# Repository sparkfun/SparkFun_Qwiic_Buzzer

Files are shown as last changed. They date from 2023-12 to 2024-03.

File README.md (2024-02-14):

SparkFun Qwiic Buzzer
========================================

SparkFun Qwiic Buzzer (https://www.sparkfun.com/products/24474)

[*SparkFun Qwiic Buzzer (BOB-24474)*](https://www.sparkfun.com/products/24474)

The SparkFun Qwiic Buzzer adds simple beeps and buzzes to your projects via I<sup>2</sup>C Make some noises to alert you when something interesting (or urgent) happens. Simply connect a Qwiic cable and load up some pre-written code to an Arduino to start making noises!

The board includes an ATtiny84 with custom firmware to control the piezoelectric buzzer over I<sup>2</sup>C. Utilizing our handy Qwiic system, no soldering is required to connect it to the rest of your system. However, we still broke out 0.1"-spaced PTH pads if you prefer to use a breadboard to access the board's I2C, power, trigger, and reset pins on the board's edge. A 2.2k&ohm; pull-up resistor is included on the data and clock lines. 

A set of transistors control the buzzer's volume. At full volume, it allows the full current of about ~95mA, which makes it _really_ loud. A flyback diode is included to discharge any energy remaining when the buzzer is turned off. For those who want to control the loudness of the buzzer, a footprint is available to solder a custom PTH resistor to one of the transistors. Just make sure to cut the jumper labeled "JP1." Two LEDs are also included on the board for power and status. 

We've written an Arduino Library to control the volume, frequency, duration, and I<sup>2</sup>C address. There are even examples of how to play a quick melody and sweet sound effects! You can download the library through the Arduino library manager by searching 'SparkFun Qwiic Buzzer,' or you can get the GitHub repo as a .zip to install the library from there manually. For those who want a simple buzz without an Arduino, you can also make noise by simply grounding the trigger pin! We've even ported the library as a Python package! 

This board is great for adding a simple audible sound to your projects. Pair the board with the Qwiic RTC to make an alarm clock, play a tune with the Qwiic RFID, or add a sound effect to your robot. So what are you waiting for?!? Start making some noise in your projects with the SparkFun Qwiic Buzzer!

Repository Contents
-------------------

* **.github/workflows** - YAML files used for GitHub Actions and GitHub Pages/mkdocs
* **/Firmware** - ATtiny84 Firmware
* **/Hardware** - Eagle design files (.brd, .sch)
  * **/Production** - Production panel files (.brd)
* **/docs** - Online documentation files
  * **/assets** - Folder containing all the file assets used for product documentation
    * **/board_files** - Copy of design files used for product documentation
    * **/component_documentation** - Datasheets and manuals for hardware components
    * **/img** - Images for product documentation
  * **/github** - Files stating how to contribute and filing issues used for product documentation
  * **/javascript** - Folder containing custom javascript used for product documentation
  * **/stylesheet** - Folder containing CSS files used for product documentation
* **/overrides** - Customization files used for product documentation
  * **/.icons** - Icons used for GitHub used for product documentation
  * **./partials** - Used for product documentation

Documentation
--------------

* **[Installing an Arduino Library Guide](https://learn.sparkfun.com/tutorials/installing-an-arduino-library)** - Basic information on how to install an Arduino library.
* **[Library](https://github.com/sparkfun/SparkFun_Qwiic_Buzzer_Arduino_Library)** - Arduino library for the Qwiic Buzzer.
* **[Hookup Guide](https://docs.sparkfun.com/SparkFun_Qwiic_Buzzer)** - Basic hookup guide for the  Qwiic Buzzer.

Product Versions
----------------
* [BOB-24474](https://www.sparkfun.com/products/24474) - v1.0

Version History
---------------
* v1.0 - Initial release

License Information
-------------------

This product is _**open source**_! 

Please review the LICENSE.md file for license information. 

If you have any questions or concerns on licensing, please contact technical support on our [SparkFun forums](https://forum.sparkfun.com/viewforum.php?f=152).

Distributed as-is; no warranty is given.

- Your friends at SparkFun.

_<COLLABORATION CREDIT>_

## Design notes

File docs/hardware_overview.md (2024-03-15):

In this section, we will highlight the hardware and pins that are broken out on the SparkFun Qwiic Buzzer.

<div style="text-align: center;">
  <table>
    <tr style="vertical-align:middle;">
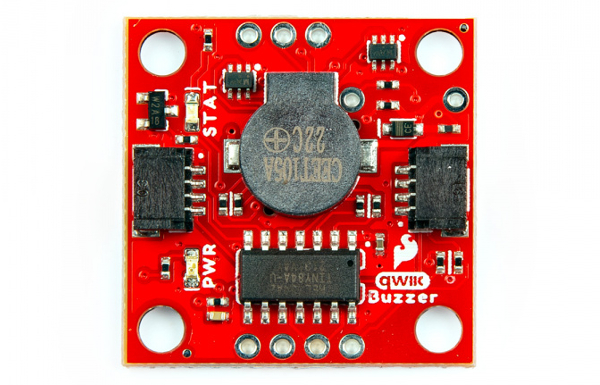
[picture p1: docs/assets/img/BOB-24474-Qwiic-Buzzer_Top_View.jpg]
Top View
     <td style="text-align: center; border: solid 1px #cccccc; vertical-align: middle;"></td>
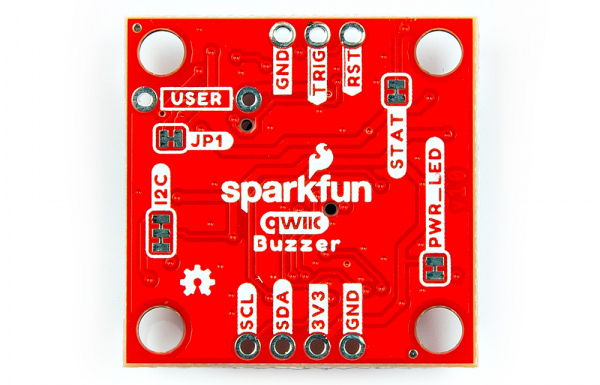
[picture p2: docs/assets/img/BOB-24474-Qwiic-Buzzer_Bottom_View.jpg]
Bottom View
     <td style="text-align: center; border: solid 1px #cccccc; vertical-align: middle;"></td>
    </tr>
    <tr style="vertical-align:middle;">
     <td style="text-align: center; border: solid 1px #cccccc; vertical-align: middle;"><i>Top View</i></td>
     <td style="text-align: center; border: solid 1px #cccccc; vertical-align: middle;"><i>Bottom View</i></td>
    </tr>
  </table>
</div>

### Power

There are a few power-related nets broken out to Qwiic connectors and through hole pads. The recommended input voltage is **3.3V**. The logic levels for the Qwiic Buzzer is **3.3V**.

* **3V3** &mdash; This connects to the 3.3V net. This net should only be provided with a clean 3.3V power signal. This is also connected to the Qwiic connectors.
* **GND** &mdash; Of course, is the common, ground voltage (0V reference) for the system.

<div style="text-align: center;">
  <table>
    <tr style="vertical-align:middle;">
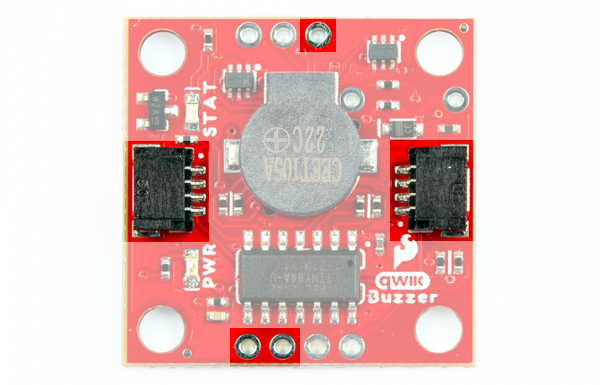
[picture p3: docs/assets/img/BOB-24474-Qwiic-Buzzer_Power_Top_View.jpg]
Power Nets Highlighted, Top View
     <td style="text-align: center; border: solid 1px #cccccc; vertical-align: middle;"></td>
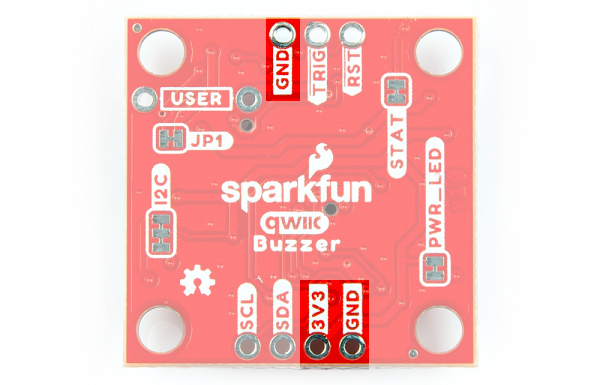
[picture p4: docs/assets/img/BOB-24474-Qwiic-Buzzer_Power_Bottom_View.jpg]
Power Nets Highlighted, Bottom View
     <td style="text-align: center; border: solid 1px #cccccc; vertical-align: middle;"></td>
    </tr>
    <tr style="vertical-align:middle;">
     <td style="text-align: center; border: solid 1px #cccccc; vertical-align: middle;"><i>Power Nets Highlighted<br />(Top View)</i></td>
     <td style="text-align: center; border: solid 1px #cccccc; vertical-align: middle;"><i>Power Nets Highlighted<br />(Bottom View)</i></td>
    </tr>
  </table>
</div>

!!! note
    While the ATtiny84 microcontroller can handle a voltage between 1.1V to 5.5V, we recommend only using 3.3V due to the fact that the Qwiic port's I<sup>2</sup>C data lines use are typically interfacing with a 3.3V system.

### Buzzer

!!! note
    Interested in the difference between a magnetic and piezo buzzer? Check out the article from CUI Devices: "[Buzzer Basics - Technologies, Tones, and Drive Circuits](https://www.cuidevices.com/blog/buzzer-basics-technologies-tones-and-driving-circuits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)".

The board would not be the Qwiic Buzzer without... a buzzer! The buzzer uses a small magnetic coil to vibrate a metal disc inside the plastic housing. By pulsating current through the coil at different rates, we can produce different frequencies (pitches) of sound.

<div style="text-align: center;">
  <table>
    <tr style="vertical-align:middle;">
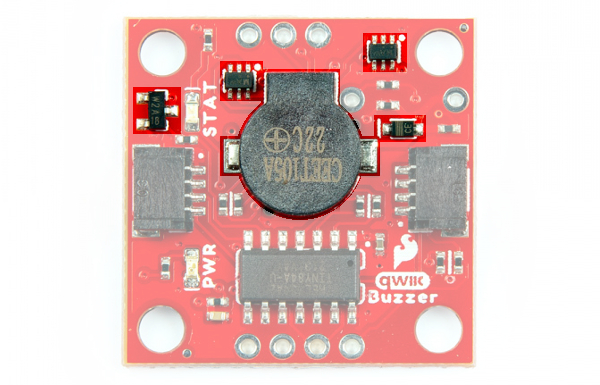
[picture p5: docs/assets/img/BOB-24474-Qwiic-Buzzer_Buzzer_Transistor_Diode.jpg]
Buzzer Highlighted
      <td style="text-align: center; border: solid 1px #cccccc; vertical-align: middle;"></td>
    </tr>
    <tr style="vertical-align:middle;">
      <td style="text-align: center; border: solid 1px #cccccc; vertical-align: middle;"><i>Buzzer Highlighted<br />(Top View)</i></td>
    </tr>
  </table>
</div>

Power and control is applied to the buzzer with a set of BJTs. At full volume, it allows the full current of about ~95mA, which makes it _really_ loud. Typically, power and control is directly connected to microcontrollers GPIO, which limits the current to ~40mA. A [flyback diode](https://learn.sparkfun.com/tutorials/diodes/all#diode-applications) is included to discharge any energy remaining when the buzzer is shut off.

### ATtiny84

The brains of the Qwiic Buzzer users an ATtiny84. This IC comes pre-programmed with custom firmware designed to interact with the Arduino Library. The ATtiny84 accepts I<sup>2</sup>C reads and writes, interprets them, and creates sound by sending a PWM signal to the buzzer. The volume of the buzzer is typically controlled using a variable resistor like a potentiometer. However, four GPIOs, NPN transistors, and resistors are used to provide 7 levels of loudness.

<div style="text-align: center;">
  <table>
    <tr style="vertical-align:middle;">
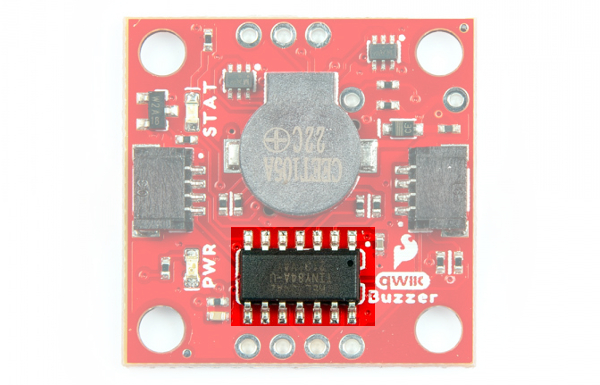
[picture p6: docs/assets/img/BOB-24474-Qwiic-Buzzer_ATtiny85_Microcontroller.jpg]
ATtiny84 microcontroller Highlighted
     <td style="text-align: center; border: solid 1px #cccccc; vertical-align: middle;"></td>
    </tr>
    <tr style="vertical-align:middle;">
      <td style="text-align: center; border: solid 1px #cccccc; vertical-align: middle;"><i>ATTiny84 Highlighted<br />(Top View)</i></td>
    </tr>
  </table>
</div>

!!! note "Where's SPI?!?"
    This board was designed to control the buzzer via I<sup>2</sup>C. While you can access the SPI pins with the help of the Eagle schematic and board files (e.g. <b><span style="text-decoration: overline">TRIG</span></b> = POCI, SDA = PICO, and SCL = SCK), these pins are only used for advanced users and programing the AVR microcontroller using custom firmware. For more information about programming an ATtiny84, check out our [Tiny AVR Programmer Hookup Guide](https://learn.sparkfun.com/tutorials/tiny-avr-programmer-hookup-guide#introduction).

### Qwiic and I<sup>2</sup>C

There are two PTHs labeled **SDA** and **SCL** on one side of the board. These indicate the I<sup>2</sup>C data and clock lines and are connected to two 2.2k&ohm; pull-up resistors. We also conveniently added a GND and 3.3V pin on one side should you decide to daisy chain additional I<sup>2</sup>C devices to the PTH. Similarly, you can use either of the Qwiic connectors to provide power and send data through I<sup>2</sup>C. The [Qwiic ecosystem](https://www.sparkfun.com/qwiic) is made for fast prototyping by removing the need for soldering. All you need to do is plug a Qwiic cable into the Qwiic connector and voila!

* **SCL** &mdash; I<sup>2</sup>C clock
* **SDA** &mdash; I<sup>2</sup>C data

<div style="text-align: center;">
  <table>
    <tr style="vertical-align:middle;">
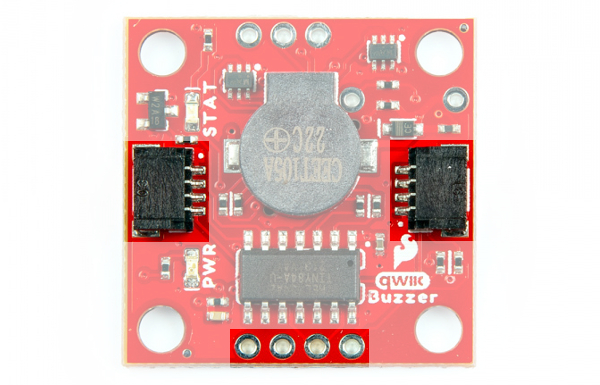
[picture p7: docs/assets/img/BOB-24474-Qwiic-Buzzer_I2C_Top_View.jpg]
Qwiic Connectors and I2C Port Highlighted
     <td style="text-align: center; border: solid 1px #cccccc; vertical-align: middle;"></td>
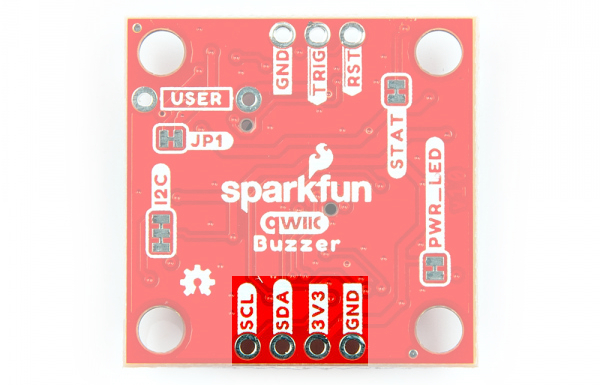
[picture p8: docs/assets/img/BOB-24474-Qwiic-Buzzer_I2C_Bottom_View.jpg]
Qwiic Connectors and I2C Port Highlighted
     <td style="text-align: center; border: solid 1px #cccccc; vertical-align: middle;"></td>
    </tr>
    <tr style="vertical-align:middle;">
     <td style="text-align: center; border: solid 1px #cccccc; vertical-align: middle;"><i>I<sup>2</sup>C PTHs Highlighted<br />(Top View)</i></td>
     <td style="text-align: center; border: solid 1px #cccccc; vertical-align: middle;"><i>Qwiic and I<sup>2</sup>C PTHs Highlighted<br />(Bottom View)</i></td>
    </tr>
  </table>
</div>

The default I<sup>2</sup>C address for the Qwiic buzzer is **0x34**. This can also be software configured.

### Broken Out Pins

* <b><span style="text-decoration: overline">TRIG</span></b> &mdash; The trigger pin enables users to active the buzzer without an I<sup>2</sup>C whenever the pin is pulled low. This pin also has an alternative function. Pulling the trigger pin low as the board is initially powered up will factory reset the board.
* <b><span style="text-decoration: overline">RST</span></b> &mdash; The reset pin resets the ATTiny84 when the pin is pulled low.

<div style="text-align: center;">
  <table>
    <tr style="vertical-align:middle;">
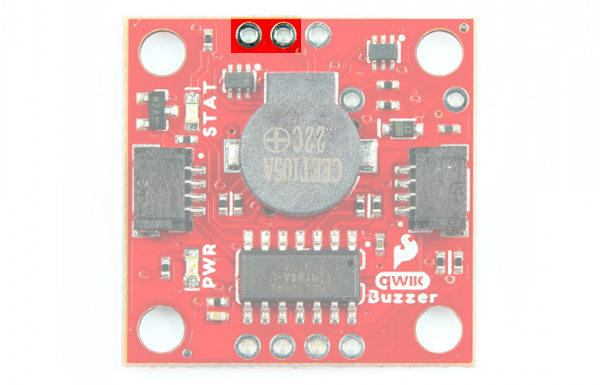
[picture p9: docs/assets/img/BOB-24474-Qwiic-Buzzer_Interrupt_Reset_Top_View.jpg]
Reset PTH Highlighted
     <td style="text-align: center; border: solid 1px #cccccc; vertical-align: middle;"></td>
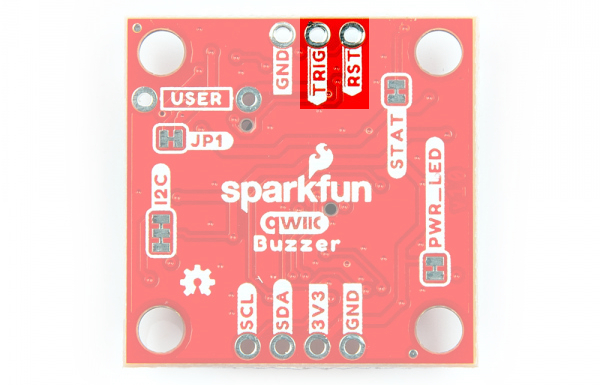
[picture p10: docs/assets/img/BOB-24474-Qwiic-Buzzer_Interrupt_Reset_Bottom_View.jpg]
Reset PTH Highlighted
     <td style="text-align: center; border: solid 1px #cccccc; vertical-align: middle;"></td>
    </tr>
    <tr style="vertical-align:middle;">
     <td style="text-align: center; border: solid 1px #cccccc; vertical-align: middle;"><i>Trigger & Reset PTHs Highlighted<br />(Top View)</i></td>
     <td style="text-align: center; border: solid 1px #cccccc; vertical-align: middle;"><i>Trigger & Reset PTHs Highlighted<br />(Bottom View)</i></td>
    </tr>
  </table>
</div>

### User Resistor

There is a footprint available for a PTH resistor. This is labeled as USER. For users interested in including a custom resistor to control the loudness of the buzzer, you can solder a PTH resistor to the two PTHs. Note that you would need to cut the jumper on the back of the board (labeled as JP1) if you are not using the onboard 2.2k&ohm; SMD resistor.

<div style="text-align: center;">
  <table>
    <tr style="vertical-align:middle;">
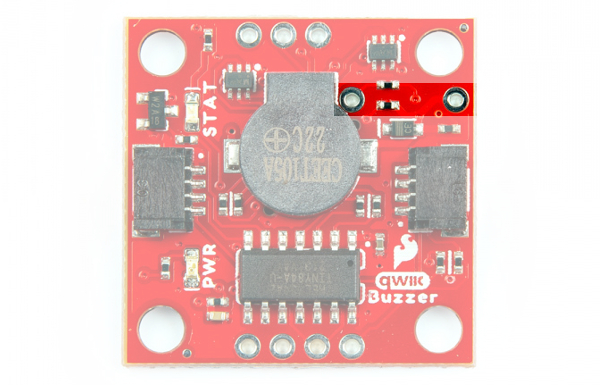
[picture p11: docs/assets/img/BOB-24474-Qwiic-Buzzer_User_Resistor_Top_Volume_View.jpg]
USER PTH resistor footprint
     <td style="text-align: center; border: solid 1px #cccccc; vertical-align: middle;"></td>
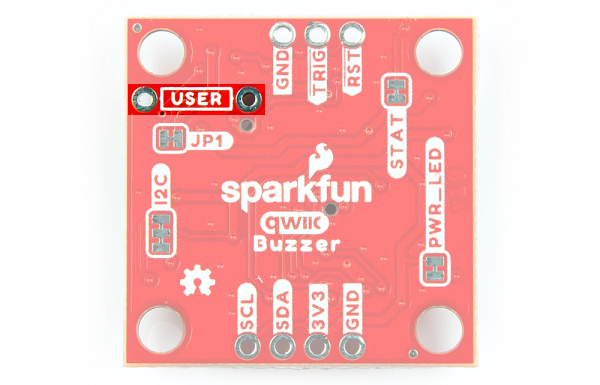
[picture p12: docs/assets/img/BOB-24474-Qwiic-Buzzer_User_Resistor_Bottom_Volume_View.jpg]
USER PTH resistor footprint
     <td style="text-align: center; border: solid 1px #cccccc; vertical-align: middle;"></td>
    </tr>
    <tr style="vertical-align:middle;">
     <td style="text-align: center; border: solid 1px #cccccc; vertical-align: middle;"><i>User Resistor PTHs Highlighted<br />(Top View)</i></td>
     <td style="text-align: center; border: solid 1px #cccccc; vertical-align: middle;"><i>User Resistor PTHs Highlighted<br />(Bottom View)</i></td>
    </tr>
  </table>
</div>

### LEDs

The board includes the following status LEDs as indicated in the image below.

* **PWR** &mdash; The power LED lights up when the board is powered. This LED is connected the 3.3V net. This LED can be disabled with the PWR jumper on the bottom of the board.
* **STAT** &mdash; The status LED lights up whenever the buzzer is active. This adds a nice visual indicator whenever there is noise.

<div style="text-align: center;">
  <table>
    <tr style="vertical-align:middle;">
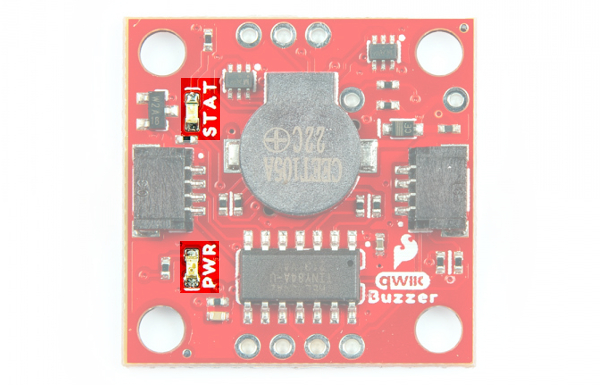
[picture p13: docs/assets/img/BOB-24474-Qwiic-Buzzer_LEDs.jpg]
LEDs Highlighted
     <td style="text-align: center; border: solid 1px #cccccc; vertical-align: middle;"></td>
    </tr>
    <tr style="vertical-align:middle;">
     <td style="text-align: center; border: solid 1px #cccccc; vertical-align: middle;"><i>LEDs Highlighted<br />(Top View)</i></td>
    </tr>
  </table>
</div>

### Jumpers

!!!note
    If this is your first time working with jumpers, check out the [How to Work with Jumper Pads and PCB Traces](https://learn.sparkfun.com/tutorials/how-to-work-with-jumper-pads-and-pcb-traces/all) tutorial for more information.

If you flip the board over, you will notice a few jumper pads.

* **PWR_LED** &mdash; The power LED will illuminate when 3.3V is available either over the Qwiic bus or the 3V3 pin. By default, this jumper is closed. Cut this jumper to disable the LED.
* **STAT** &mdash; The status LED will illuminate whenever the buzzer is making noise. By default, this jumper is closed. Cut this jumper to disable the LED.
* **I2C** &mdash; This three way jumper labeled **I2C** is connected to two pull-up resistors on the I<sup>2</sup>C data and clock lines. For users that have multiple Qwiic-enabled devices with pull-up resistors enabled, the parallel equivalent resistance will create too strong of a pull-up for the bus to operate correctly. As a general rule of thumb, [disable all but one pair of pull-up resistors](https://learn.sparkfun.com/tutorials/i2c/all#i2c-at-the-hardware-level) if multiple devices are connected to the bus.
* **JP1** &mdash; This jumper pad is available for users that want include a custom resistor to control the loudness of the buzzer. Cut this jumper to disconnect resistor R15. You will need to have a resistor populated for the USER PTH resistor.

<div style="text-align: center;">
  <table>
    <tr style="vertical-align:middle;">
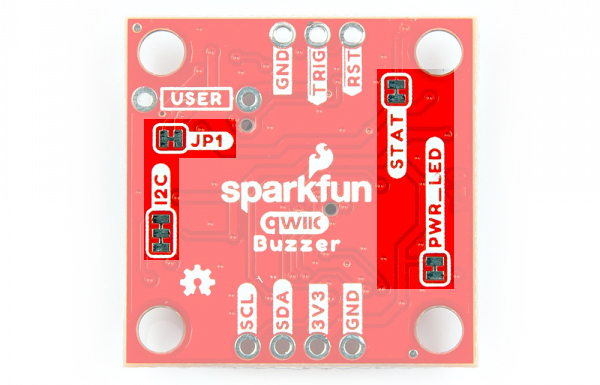
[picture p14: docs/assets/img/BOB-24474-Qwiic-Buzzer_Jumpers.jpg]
Jumpers Highlighted
     <td style="text-align: center; border: solid 1px #cccccc; vertical-align: middle;"></td>
    </tr>
    <tr style="vertical-align:middle;">
     <td style="text-align: center; border: solid 1px #cccccc; vertical-align: middle;"><i>Jumpers Highlighted<br />(Bottom View)</i></td>
    </tr>
  </table>
</div>

### Board Dimensions

The board uses the standard 1.0" x 1.0" (25.4mm x 25.4mm) Qwiic board. There are 4x mounting holes by each corner of the board.

<div style="text-align: center;">
  <table>
    <tr style="vertical-align:middle;">
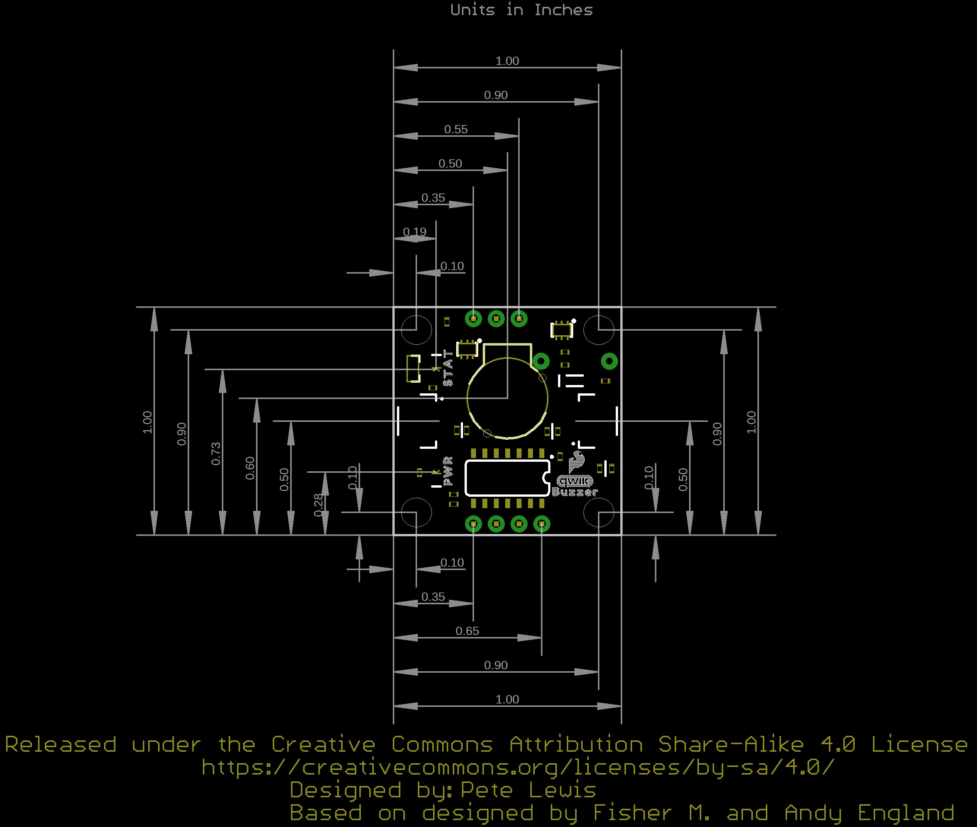
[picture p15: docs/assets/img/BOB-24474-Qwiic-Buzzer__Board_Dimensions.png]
Board Dimensions
     <td style="text-align: center; border: solid 1px #cccccc; vertical-align: middle;"></td>
    </tr>
    <tr style="vertical-align:middle;">
     <td style="text-align: center; border: solid 1px #cccccc; vertical-align: middle;"><i>Board Dimensions</i></td>
    </tr>
  </table>
</div>

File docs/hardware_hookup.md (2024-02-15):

In this section, we'll go over how to connect the Qwiic Buzzer to an Arduino microcontroller.

### Connecting to the Qwiic I<sup>2</sup>C Port

Insert a Qwiic cable between the Qwiic Buzzer and your Arduino microcontroller. Then connect a USB cable between the Arduino microcontroller and your computer's COM port. In this case, we used the RedBoard Plus with ATmega328P.

<div style="text-align: center;">
  <table>
    <tr style="vertical-align:middle;">
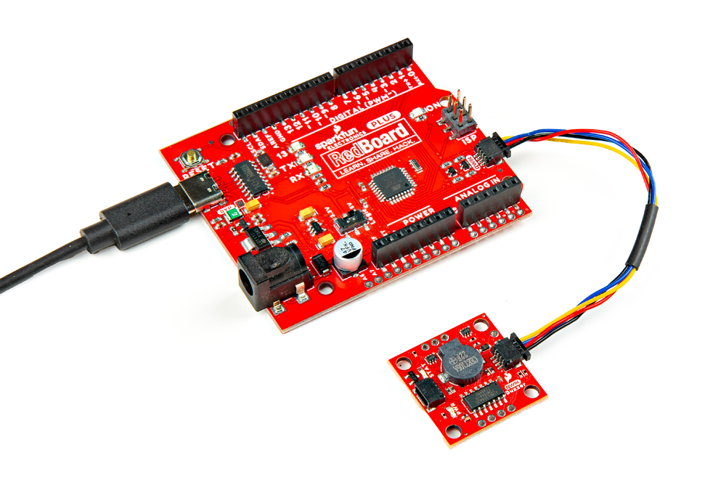
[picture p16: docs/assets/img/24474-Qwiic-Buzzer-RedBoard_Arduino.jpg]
RedBoard ATmega328P Programmed with Arduino Connected to Qwiic Buzzer
     <td style="text-align: center; border: solid 1px #cccccc; vertical-align: middle;"></td>
    </tr>
    <tr style="vertical-align:middle;">
     <td style="text-align: center; border: solid 1px #cccccc; vertical-align: middle;"><i>RedBoard ATmega328P Programmed with Arduino Connected to Qwiic Buzzer</i></td>
    </tr>
  </table>
</div>

With the Qwiic Buzzer, you can daisy chain more than one buzzer! Typically on an Arduino, you could only use the [`tone()` function](https://www.arduino.cc/reference/en/language/functions/advanced-io/tone/) with one buzzer at a time and the function could also interfere with other PWM output pins as well. Controlling the Qwiic Buzzer through I<sup>2</sup>C allows you to play multiple buzzers simultaneously. Just make sure to configure the address of the buzzer and make another instance of any additional buzzer in the code should you decide to control each buzzer separately.

<div style="text-align: center;">
  <table>
    <tr style="vertical-align:middle;">
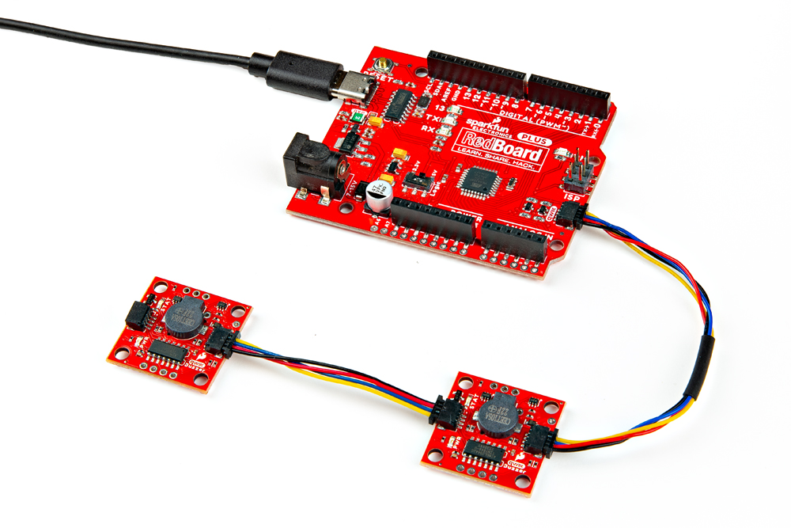
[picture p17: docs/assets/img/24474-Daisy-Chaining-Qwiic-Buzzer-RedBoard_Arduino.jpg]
RedBoard ATmega328P Programmed with Arduino Connected Two Qwiic Buzzers
     <td style="text-align: center; border: solid 1px #cccccc; vertical-align: middle;"></td>
    </tr>
    <tr style="vertical-align:middle;">
     <td style="text-align: center; border: solid 1px #cccccc; vertical-align: middle;"><i>RedBoard ATmega328P Programmed with Arduino Connected Two Qwiic Buzzers</i></td>
    </tr>
  </table>
</div>

!!! note
    When daisy chaining both boards, you can control both simultaneously when using the same address.

### Connecting via PTH

For temporary connections to the PTHs on the edge of the board, you could use IC hooks to test out the pins. However, you'll need to solder headers or wires of your choice to the board for a secure connection. You can choose between a combination of [header pins and jumper wires](https://learn.sparkfun.com/tutorials/how-to-solder-through-hole-soldering/all), or [stripping wire and soldering the wire](https://learn.sparkfun.com/tutorials/working-with-wire/all) directly to the board.

<div class="grid cards hide col-4" markdown>

-   <a href="https://learn.sparkfun.com/tutorials/how-to-solder-through-hole-soldering/all">
      <figure markdown>
        How to Solder: Through Hole Soldering
      </figure>
    </a>

    ---

    <a href="https://learn.sparkfun.com/tutorials/how-to-solder-through-hole-soldering/all">
      <b>How to Solder: Through Hole Soldering</b>
    </a>
<!-- ----------WHITE SPACE BETWEEN GRID CARDS---------- -->

-   <a href="https://learn.sparkfun.com/tutorials/working-with-wire/all">
      <figure markdown>
        Working with Wire
      </figure>
    </a>

    ---

    <a href="https://learn.sparkfun.com/tutorials/working-with-wire/all">
      <b>Working with Wire</b>
    </a>
<!-- ----------WHITE SPACE BETWEEN GRID CARDS---------- -->
</div>

For the custom resistor, you will need to bend the resistor's terminals and insert it into the PTHs where it says USER. You can solder the terminals from the bottom or top. Depending on the size of the resistor, the resistor may not sit flush against the board. You may need to bend the terminals in and push the resistor to the side. The image shown below on the left shows a 1/4 watt resistor with thick leads not sitting flush against the footprint. For those inserting the  resistor from the bottom, make sure to have enough room to cut the jumper labeled as JP1 before soldering the resistor's terminals. Of course, make sure to cut off the excess terminals after soldering the resistor and carefully clean the board.

<div style="text-align: center;">
  <table>
    <tr style="vertical-align:middle;">
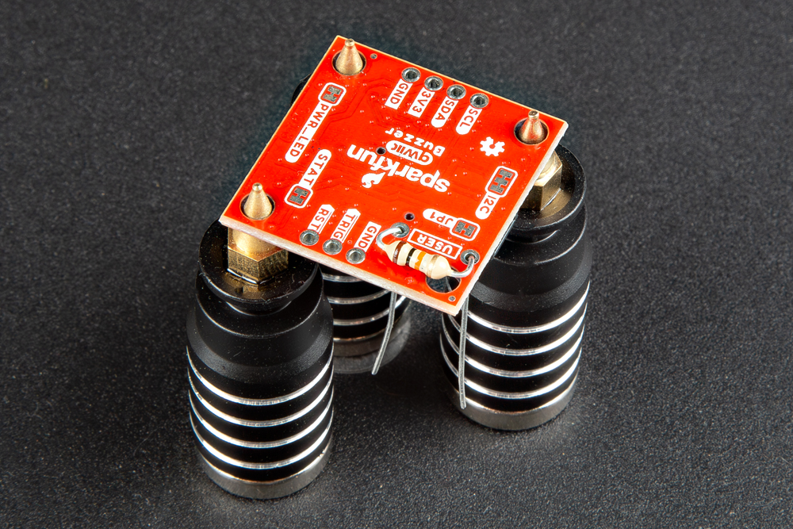
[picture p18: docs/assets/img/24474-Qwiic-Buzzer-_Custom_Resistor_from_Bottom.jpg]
Soldering Custom Resistor
     <td style="text-align: center; border: solid 1px #cccccc; vertical-align: middle;"></td>
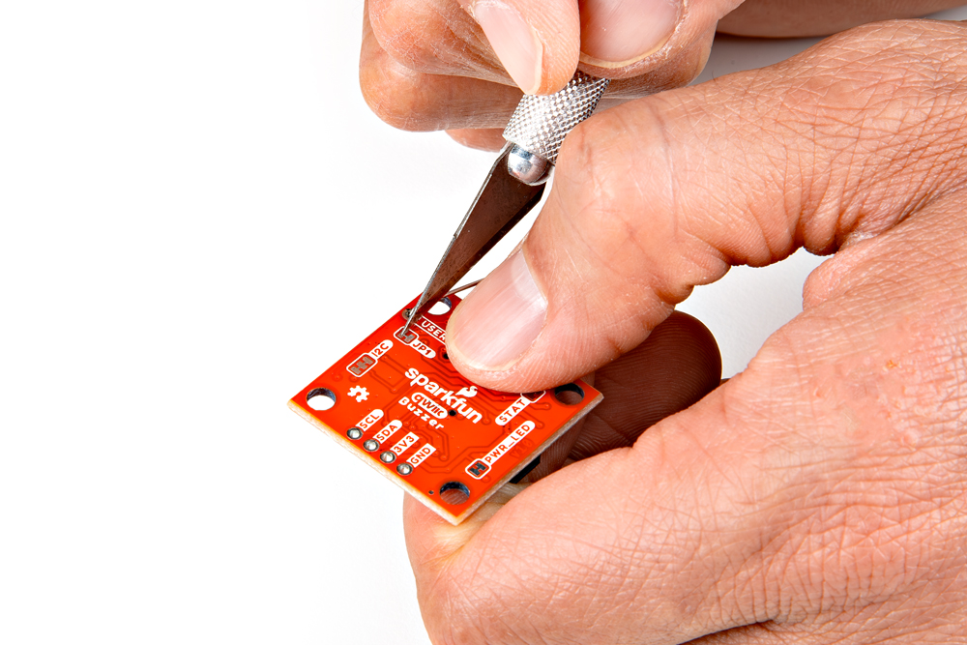
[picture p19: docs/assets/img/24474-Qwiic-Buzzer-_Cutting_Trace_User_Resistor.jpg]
     <td style="text-align: center; border: solid 1px #cccccc; vertical-align: middle;"></td>
    </tr>
    <tr style="vertical-align:middle;">
      <td style="text-align: center; border: solid 1px #cccccc; vertical-align: middle;"><i>Cut JP1 Jumper</i></td>
      <td style="text-align: center; border: solid 1px #cccccc; vertical-align: middle;"><i>Soldering Custom Resistor</i></td>
    </tr>
  </table>
</div>

!!! warning
    When cleaning the board, make sure that the buzzer is not submerged under water.

You can also carefully pull the two inner pins out of a 1x4 standard male header pin using pliers, solder the remaining two into the board, and insert the Qwiic Buzzerinto a breadboard. This is useful for those interested in using a 10k&ohm; potentiometer to control the volume.

<div style="text-align: center;">
  <table>
    <tr style="vertical-align:middle;">
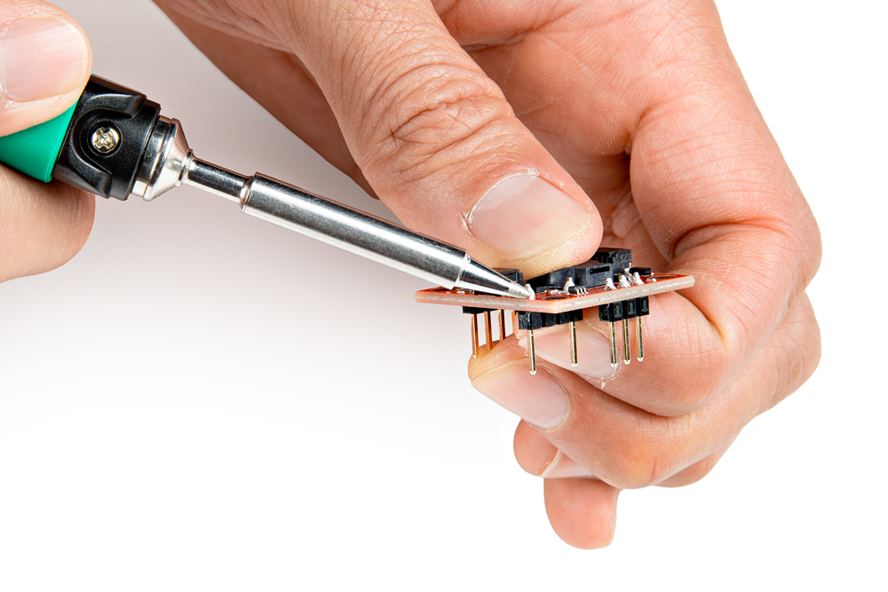
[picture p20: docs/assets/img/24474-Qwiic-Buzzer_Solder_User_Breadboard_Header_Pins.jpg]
     <td style="text-align: center; border: solid 1px #cccccc; vertical-align: middle;"></td>
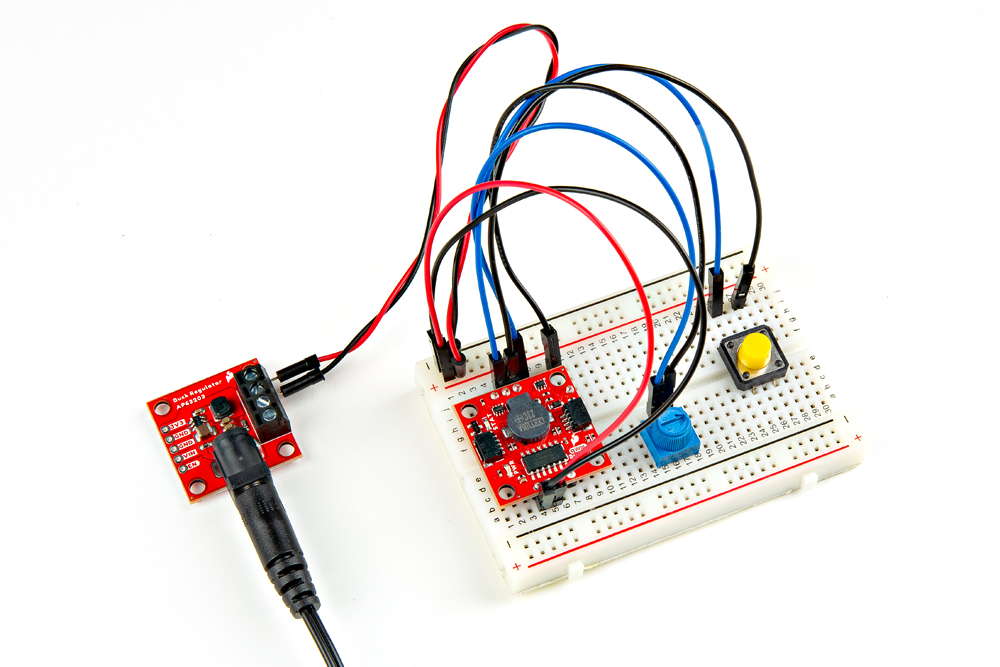
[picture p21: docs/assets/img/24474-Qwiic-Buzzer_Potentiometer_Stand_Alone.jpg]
     <td style="text-align: center; border: solid 1px #cccccc; vertical-align: middle;"></td>
    </tr>
    <tr style="vertical-align:middle;">
      <td style="text-align: center; border: solid 1px #cccccc; vertical-align: middle;"><i>Soldering 1x4 Header Pins (with Center Pins Pulled Out)</i></td>
      <td style="text-align: center; border: solid 1px #cccccc; vertical-align: middle;"><i>Soldering Custom Resistor</i></td>
    </tr>
  </table>
</div>

!!! note
    By sacrificing two inner male pins from the 1x4 header, the remaining plastic spacers will help keep the single square pins in place as you solder them to the board.

### Stand-Alone Mode

For users that simply need to trigger a beeping noise, all you need to do is power the Qwiic Buzzer and ground the trigger pin! If you have a 3.3V voltage regulator, simply connect 3.3V and ground to the Qwiic Buzzer. Then connect the <b><span style="text-decoration: overline">TRIG</span></b> pin to GND using either a momentary button or jumper wire.

<div style="text-align: center;">
    <table>
        <tr>
            <th style="text-align: center; border: solid 1px #cccccc;">SparkFun Buck Regulator Breakout<br />3.3V (AP63203) Pins
            </th>
            <th style="text-align: center; border: solid 1px #cccccc;">Button
            </th>
            <th style="text-align: center; border: solid 1px #cccccc;">Qwiic Buzzer<br />Pins
            </th>
        </tr>
        <tr style="vertical-align:middle;">
            <td style="text-align: center; border: solid 1px #cccccc;" bgcolor="#f2dede"><font color="#000000">3V3</font>
            </td>
            <td style="text-align: center; border: solid 1px #cccccc;"><font color="#000000"></font>
            </td>
            <td style="text-align: center; border: solid 1px #cccccc;" bgcolor="#f2dede"><font color="#000000">3V3</font>
            </td>
        </tr>
        <tr style="vertical-align:middle;">        
            <td style="text-align: center; border: solid 1px #cccccc;" bgcolor="#DDDDDD"><font color="#000000">GND</font>
            </td>
            <td style="text-align: center; border: solid 1px #cccccc;" bgcolor="#DDDDDD"><font color="#000000">Common</font>
            </td>
            <td style="text-align: center; border: solid 1px #cccccc;" bgcolor="#DDDDDD"><font color="#000000">GND</font>
            </td>
        </tr>
        <tr style="vertical-align:middle;">        
            <td style="text-align: center; border: solid 1px #cccccc;"><font color="#000000"></font>
            </td>
            <td style="text-align: center; border: solid 1px #cccccc;" bgcolor="#fff3cd"><font color="#000000">Normally Open (NO)</font>
            </td>
            <td style="text-align: center; border: solid 1px #cccccc;" bgcolor="#fff3cd"><font color="#000000">TRIG</font>
            </td>
        </tr>
    </table>
</div>

<div style="text-align: center;">
  <table>
    <tr style="vertical-align:middle;">
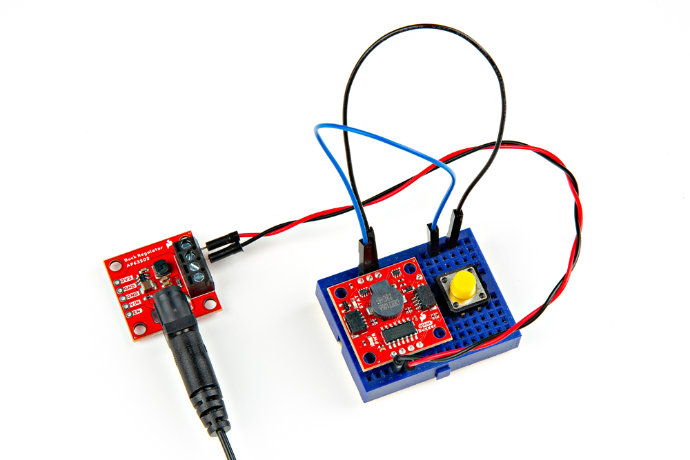
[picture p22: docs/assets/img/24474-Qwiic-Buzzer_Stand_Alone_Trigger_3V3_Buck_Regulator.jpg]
Buck Regulator Breakout - 3.3V (AP63203), Qwiic Buzzer, and Button
     <td style="text-align: center; border: solid 1px #cccccc; vertical-align: middle;"></td>
    </tr>
    <tr style="vertical-align:middle;">
     <td style="text-align: center; border: solid 1px #cccccc; vertical-align: middle;"><i>Toggling Trigger Pin with a Button</i></td>
    </tr>
  </table>
</div>

<div style="text-align: center;">
    <table>
    <tr style="vertical-align:middle;">
            <th style="text-align: center; border: solid 1px #cccccc;">SparkFun Buck Regulator Breakout<br />3.3V (AP63203) Pins
            </th>
            <th style="text-align: center; border: solid 1px #cccccc;">Button
            </th>
            <th style="text-align: center; border: solid 1px #cccccc;">10k&ohm; Trim Pot
            </th>
            <th style="text-align: center; border: solid 1px #cccccc;">Qwiic Buzzer<br />Pins
            </th>
        </tr>
        <tr style="vertical-align:middle;">
            <td style="text-align: center; border: solid 1px #cccccc;" bgcolor="#f2dede"><font color="#000000">3V3</font>
            </td>
            <td style="text-align: center; border: solid 1px #cccccc;"><font color="#000000"></font>
            </td>
            <td style="text-align: center; border: solid 1px #cccccc;" ><font color="#000000"></font>
            </td>
            <td style="text-align: center; border: solid 1px #cccccc;" bgcolor="#f2dede"><font color="#000000">3V3</font>
            </td>
        </tr>
        <tr style="vertical-align:middle;">     
            <td style="text-align: center; border: solid 1px #cccccc;" bgcolor="#DDDDDD"><font color="#000000">GND</font>
            </td>
            <td style="text-align: center; border: solid 1px #cccccc;" bgcolor="#DDDDDD"><font color="#000000">Common</font>
            </td>
            <td style="text-align: center; border: solid 1px #cccccc;"><font color="#000000"></font>
            </td>
            <td style="text-align: center; border: solid 1px #cccccc;" bgcolor="#DDDDDD"><font color="#000000">GND</font>
            </td>
        </tr>
        <tr style="vertical-align:middle;">        
            <td style="text-align: center; border: solid 1px #cccccc;"><font color="#000000"></font>
            </td>
            <td style="text-align: center; border: solid 1px #cccccc;" bgcolor="#fff3cd"><font color="#000000">Normally Open (NO)</font>
            </td>
            <td style="text-align: center; border: solid 1px #cccccc;"><font color="#000000"></font>
            </td>
            <td style="text-align: center; border: solid 1px #cccccc;" bgcolor="#fff3cd"><font color="#000000">TRIG</font>
            </td>
        </tr>
        <tr style="vertical-align:middle;">        
            <td style="text-align: center; border: solid 1px #cccccc;"><font color="#000000"></font>
            </td>
            <td style="text-align: center; border: solid 1px #cccccc;"><font color="#000000"></font>
            </td>
            <td style="text-align: center; border: solid 1px #cccccc;" bgcolor="#cce5ff"><font color="#000000">Pin 2<br />(i.e. Center Pin)</font>
            </td>
            <td style="text-align: center; border: solid 1px #cccccc;" bgcolor="#cce5ff"><font color="#000000">USER PTH 1<br />(The PTH closest<br />to the Buzzer)</font>
            </td>
        </tr>
        <tr style="vertical-align:middle;">       
            <td style="text-align: center; border: solid 1px #cccccc;"><font color="#000000"></font>
            </td>
            <td style="text-align: center; border: solid 1px #cccccc;"><font color="#000000"></font>
            </td>
            <td style="text-align: center; border: solid 1px #cccccc;" bgcolor="#d4edda"><font color="#000000">Pin 1 or 3</font>
            </td>
            <td style="text-align: center; border: solid 1px #cccccc;" bgcolor="#d4edda"><font color="#000000">USER PTH 2<br />(The PTH closest<br />to the Qwiic Connector)</font>
            </td>
        </tr>
    </table>
</div>

<div style="text-align: center;">
  <table>
    <tr style="vertical-align:middle;">
     <td style="text-align: center; border: solid 1px #cccccc; vertical-align: middle;"><a href="../assets/img/24474-Qwiic-Buzzer_Potentiometer_Stand_Alone.jpg">Buck Regulator Breakout - 3.3V (AP63203), Qwiic Buzzer, Button and 10kOhm Trimpot</a></td>
    </tr>
    <tr style="vertical-align:middle;">
     <td style="text-align: center; border: solid 1px #cccccc; vertical-align: middle;"><i>Toggling Trigger Pin with a Button While Controlling Volume with 10k&ohm; Trimpot</i></td>
    </tr>
  </table>
</div>

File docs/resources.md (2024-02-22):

Now that you've successfully got your SparkFun Qwiic Buzzer up and running, it's time to incorporate it into your own project! This board is great for adding a simple audible sound to your projects. Pair board with the Qwiic RTC to make an alarm clock, play a tune with the Qwiic RFID, or add a sound effect to your robot. So what are you waiting for?!? Start making some noise in your projects with the SparkFun Qwiic Buzzer! For more information, check out the resources below:

* [Schematic (PDF)](../assets/board_files/SparkFun_Qwiic_Buzzer_Schematic_V10.pdf)
* [Eagle Files (ZIP)](../assets/board_files/SparkFun_Qwiic_Buzzer_V10.zip)
* [Board Dimensions (PNG)](../assets/img/BOB-24474-Qwiic-Buzzer__Board_Dimensions.png)
* Datasheet
    * [ATtiny84](../assets/component_documentation/ATTINY84_Datasheet_doc8006.pdf)
    * [CBT-09427-SMT-TR Magnetic Buzzer](../assets/component_documentation/cbt-09427-smt-tr.pdf)
* [Qwiic Info Page](https://www.sparkfun.com/qwiic)
* [Arduino Library](https://github.com/sparkfun/SparkFun_Qwiic_Buzzer_Arduino_Library)
* [ReadtheDocs: Qwiic Buzzer](https://qwiic-buzzer-py.readthedocs.io/en/latest/)
* [Qwiic Buzzer Python Package](https://github.com/sparkfun/Qwiic_Buzzer_Py)
* [GitHub Hardware Repo](https://github.com/sparkfun/SparkFun_Qwiic_Buzzer)

Or check out this blog post for ideas.

<div class="grid cards" style="width:500px;" markdown>
<!-- ----------WHITE SPACE BETWEEN GRID CARDS---------- -->
-   <a href="https://www.sparkfun.com/news/9910">
      <figure markdown>
        Raising your Buzzer Projects to the Next Level
      </figure>
    </a>

    ---

    <a href="https://www.sparkfun.com/news/9910">
      <b>Raising your Buzzer Projects to the Next Level</b>
    </a>
<!-- ----------WHITE SPACE BETWEEN GRID CARDS---------- -->
</div>

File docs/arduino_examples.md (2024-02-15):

Now that we have our library installed, we can get started experimenting with the breakout board. For the scope of this tutorial, we will highlight the examples. From there we will be able to build our own custom code to integrate the Qwiic Buzzer into a project.

### Example 1: Buzz

In this example, we will show how to turn on and off the buzzer. This is similar to the classic "blink" sketch using an LED.

Open the example by heading to: **File** > **Examples** > **Qwiic Buzzer** > **Example_01_Buzz**. If you have not already, select your Board (in this case, the **Arduino Uno**), and associated COM port. Upload the code to the board. You should hear the Qwiic buzzer turning on and off every second.

<div style="text-align: center;">
  <table>
    <tr style="vertical-align:middle;">
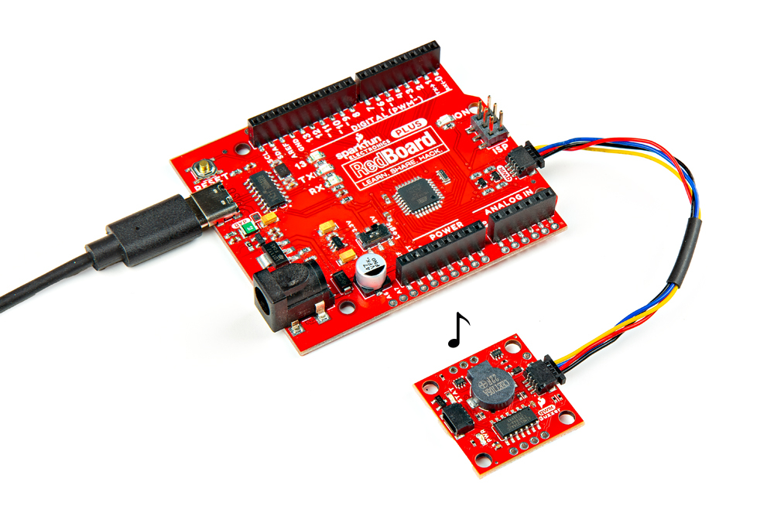
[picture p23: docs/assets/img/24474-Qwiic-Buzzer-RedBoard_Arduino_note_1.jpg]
RedBoard ATmega328P Programmed with Arduino Connected to Qwiic Buzzer, with note
     <td style="text-align: center; border: solid 1px #cccccc; vertical-align: middle;"></td>
    </tr>
  </table>
</div>

### Example 2: Buzz Frequency

In this example, we will turn on and off the buzzer similar to the previous example. However, we will show how to adjust the frequency of the buzz every second.

Open the example by heading to: **File** > **Examples** > **Qwiic Buzzer** > **Example_02_Buzz_Frequency**. If you have not already, select your Board (in this case, the **Arduino Uno**), and associated COM port. Upload the code to the board.

<div style="text-align: center;">
  <table>
    <tr style="vertical-align:middle;">
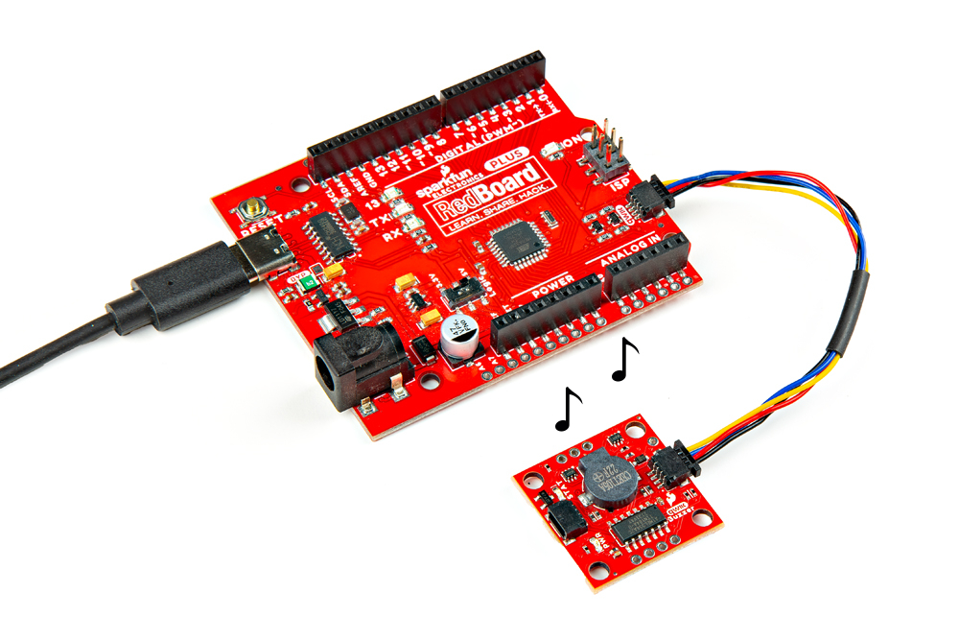
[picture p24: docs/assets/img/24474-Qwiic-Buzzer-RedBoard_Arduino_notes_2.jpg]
RedBoard ATmega328P Programmed with Arduino Connected to Qwiic Buzzer, with notes
     <td style="text-align: center; border: solid 1px #cccccc; vertical-align: middle;"></td>
    </tr>
  </table>
</div>

 Try adjusting the frequency between values around `31` to `11000` to get the desired sound or `0` for a "rest." Of course, `buzzer.configureBuzzer()` also accepts [macros that were originally defined for pitches.h](https://github.com/sparkfun/SparkFun_Qwiic_Buzzer_Arduino_Library/blob/main/src/sfeQwiicBuzzerPitches.h) as well.

!!! note
    The first parameter that [`buzzer.configureBuzzer()](https://github.com/sparkfun/SparkFun_Qwiic_Buzzer_Arduino_Library/blob/b482bc7a6ee02bfbf9cffa0da09453260b7133a0/src/sfeQwiicBuzzer.cpp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) takes is a unsigned 16-bit integer. Technically, the function can accept values between 0 to 65,535. However, the human hearing range is between 20 to 20,000 Hz. Testing the Qwiic Buzzer, we found that the range is between around 30Hz to 11,000Hz. Outside of this range, you would just hear a click.

### Example 3: Buzz Duration

In this example, we will turn on and off the buzzer similar to the previous two examples. However, will adjust the duration as well.

Open the example by heading to: **File** > **Examples** > **Qwiic Buzzer** > **Example_03_Buzz_Duration**. If you have not already, select your Board (in this case, the **Arduino Uno**), and associated COM port. Upload the code to the board.

<div style="text-align: center;">
  <table>
    <tr style="vertical-align:middle;">
     <td style="text-align: center; border: solid 1px #cccccc; vertical-align: middle;"><a href="../assets/img/24474-Qwiic-Buzzer-RedBoard_Arduino_notes_3.jpg">RedBoard ATmega328P Programmed with Arduino Connected to Qwiic Buzzer, with long note</a></td>
    </tr>
  </table>
</div>

Try adjusting the second parameter for `buzzer.configureBuzzer()` duration in milliseconds. When the buzzer is on, you will want to be careful about the duration exceeding the `delay()` function. For example, if the duration is longer than the `delay()` and a second `buzzer.configureBuzzer()` is executed to make another note, the second `buzzer.configureBuzzer()` will "over-write" the previous note and play the second note.

!!! note
    The second parameter that [`buzzer.configureBuzzer()``](https://github.com/sparkfun/SparkFun_Qwiic_Buzzer_Arduino_Library/blob/b482bc7a6ee02bfbf9cffa0da09453260b7133a0/src/sfeQwiicBuzzer.cpp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) takes is also an unsigned 16-bit integer. The function can accept values between 0 to 65,535.

### Example 4: Buzz Volume

In this example, we will turn on and off the buzzer similar to the first example. However, we will toggle each transistor to increase the volume of the buzz.

Open the example by heading to: **File** > **Examples** > **Qwiic Buzzer** > **Example_04_Buzz_Volume**. If you have not already, select your Board (in this case, the **Arduino Uno**), and associated COM port. Upload the code to the board.

<div style="text-align: center;">
  <table>
    <tr style="vertical-align:middle;">
     <td style="text-align: center; border: solid 1px #cccccc; vertical-align: middle;"><a href="../assets/img/24474-Qwiic-Buzzer-RedBoard_Arduino_notes_4.jpg">RedBoard ATmega328P Programmed with Arduino Connected to Qwiic Buzzer, with small and big notes to denote volume</a></td>
    </tr>
  </table>
</div>

Notice that the example code uses predefined macros to control each of the transistors: `SFE_QWIIC_BUZZER_VOLUME_MIN`, `SFE_QWIIC_BUZZER_VOLUME_LOW`, `SFE_QWIIC_BUZZER_VOLUME_MID`, `SFE_QWIIC_BUZZER_VOLUME_MAX`. To turn off all the transistors, you would use `SFE_QWIIC_BUZZER_VOLUME_OFF`. For users that are using a custom resistor or potentiometer, you will need to use the `SFE_QWIIC_BUZZER_VOLUME_MIN`. Just make sure to cut the jumper labeled as `JP1`.

### Example 5: Change I2C Address

In this example, we will change the default address of the buzzer from **0x34** to a different value between ranging from **0x08** and **0x77**.

Open the example by heading to: **File** > **Examples** > **Qwiic Buzzer** > **Example_05_Change_I2C_Address**. If you have not already, select your Board (in this case, the **Arduino Uno**), and associated COM port. Upload the code to the board.

After uploading code, open the [Arduino Serial Monitor](https://learn.sparkfun.com/tutorials/terminal-basics/all#arduino-serial-monitor-windows-mac-linux) and set it to **115200** baud. You will also need to specify the line ending by setting it to: `Both NL & CR`. You will find this option to the left of the drop down menu for the baud rate.

<div style="text-align: center;">
  <table>
    <tr style="vertical-align:middle;">
     <td style="text-align: center; border: solid 1px #cccccc; vertical-align: middle;"><a href="../assets/img/Arduino_Qwiic_Buzzer_Change_I2C_Address.JPG">Changing I2C Address</a></td>
    </tr>
  </table>
</div>

Send a new [hexadecimal](https://learn.sparkfun.com/tutorials/hexadecimal/all) address ranging from **0x08** to  **0x77**, but without the prefix **0x**. Let's follow the message that was output to the Arduino Serial Monitor by typing <kbd>5B</kbd> and hitting the <kbd>ENTER</kbd> button.

<div style="text-align: center;">
  <table>
    <tr style="vertical-align:middle;">
     <td style="text-align: center; border: solid 1px #cccccc; vertical-align: middle;"><a href="../assets/img/Arduino_Qwiic_Buzzer_Changed_I2C_Address.JPG">Changed I2C Address</a></td>
    </tr>
  </table>
</div>

Once the address is changed, the example code will begin to search for any addresses on the I<sup>2</sup>C bus. You should be able to see the new address of the Qwiic Buzzer. Now that we have changed address, try looking at example 10 to see the how to connect Qwiic Buzzer with a new address.

### Example 6: Save Settings

In this example, we will show how to save settings to the buzzer. We will configure the buzzer, make a buzz, and save the settings to memory. Every time we configure the Qwiic Buzzer's characteristics (frequency, duration, or volume), the buzzer will continue to play a buzz with the same settings until we send the **.configureBuzzer()** function different values or when power is cycled.

Open the example by heading to: **File** > **Examples** > **Qwiic Buzzer** > **Example_06_SaveSettings**. If you have not already, select your Board (in this case, the **Arduino Uno**), and associated COM port. Upload the code to the board.

<div style="text-align: center;">
  <table>
    <tr style="vertical-align:middle;">
     <td style="text-align: center; border: solid 1px #cccccc; vertical-align: middle;"><a href="../assets/img/Arduino_Qwiic_Buzzer_Save_Settings.JPG">Save Settings</a></td>
    </tr>
  </table>
</div>

Power cycle the Qwiic Buzzer. Grab a M/M jumper wire. Connect one end to any ground pin (GND). When ready, connect the other end of the jumper wire to the trigger pin (<span style="text-decoration: overline">TRIG</span>). You should be able to hear the same sound every time the pin is pulled low whenever power is removed.

!!! note
    Pulling the trigger pin low as the board is initially powered up will factory reset the board.

### Example 7: Buzz Melody

In this example, we will play a melody once.

Open the example by heading to: **File** > **Examples** > **Qwiic Buzzer** > **Example_07_Melody**. If you have not already, select your Board (in this case, the **Arduino Uno**), and associated COM port. Upload the code to the board.

After uploading code, you should hear the melody play one time.

<div style="text-align: center;">
  <table>
    <tr style="vertical-align:middle;">
     <td style="text-align: center; border: solid 1px #cccccc; vertical-align: middle;"><a href="../assets/img/24474-Qwiic-Buzzer-RedBoard_Arduino_notes_5.jpg">RedBoard ATmega328P Programmed with Arduino Connected to Qwiic Buzzer, with melody</a></td>
    </tr>
  </table>
</div>

### Example 8: Sound Effects

In this example, we will play different sound effects once.

 Open the example by heading to: **File** > **Examples** > **Qwiic Buzzer** > **Example_08_Sound_Effects**. If you have not already, select your Board (in this case, the **Arduino Uno**), and associated COM port. Upload the code to the board.

 After uploading code, sit back and enjoy the sweet sound effects!

 <div style="text-align: center;">
   <table>
     <tr style="vertical-align:middle;">
      <td style="text-align: center; border: solid 1px #cccccc; vertical-align: middle;"><a href="../assets/img/24474-Qwiic-Buzzer-RedBoard_Arduino_notes_6.jpg">RedBoard ATmega328P Programmed with Arduino Connected to Qwiic Buzzer, with sound effects</a></td>
     </tr>
   </table>
 </div>

### Example 9: Firmware Version

In this example, we will check the firmware version that is flashed on the ATtiny84.

 Open the example by heading to: **File** > **Examples** > **Qwiic Buzzer** > **Example_09_FirmwareVersion**. If you have not already, select your Board (in this case, the **Arduino Uno**), and associated COM port. Upload the code to the board.

After uploading code, open the [Arduino Serial Monitor](https://learn.sparkfun.com/tutorials/terminal-basics/all#arduino-serial-monitor-windows-mac-linux) and set it to **115200** baud. You should be able to see the current firmware loaded on the Qwiic Buzzer's ATtiny84.

<div style="text-align: center;">
  <table>
    <tr style="vertical-align:middle;">
     <td style="text-align: center; border: solid 1px #cccccc; vertical-align: middle;"><a href="../assets/img/Arduino_Qwiic_Buzzer_Firmware_Version.JPG">Qwiic Buzzer's Current Firmware Version</a></td>
    </tr>
  </table>
</div>

### Example 10: Buzz Multiple

In this example, we will show how to control two Qwiic Buzzers with different addresses. If you have not already, check out [example 5](../arduino_examples/#example-5-change-i2c-address) to change the address of one of the Qwiic Buzzers. This example expects two buzzers set to these unique I<sup>2</sup>C addresses: **0x34** and **0x5B**.

 Open the example by heading to: **File** > **Examples** > **Qwiic Buzzer** > **Example_10_Buzz_Multiple**. If you have not already, select your Board (in this case, the **Arduino Uno**), and associated COM port. Upload the code to the board.

 Once the code has been uploaded, the buzzer with default address will buzz first. The second buzzer with the other address will make a buzz shortly after before the code loops again.

 <div style="text-align: center;">
   <table>
     <tr style="vertical-align:middle;">
      <td style="text-align: center; border: solid 1px #cccccc; vertical-align: middle;"><a href="../assets/img/24474-Daisy-Chaining-Qwiic-Buzzer-RedBoard_Arduino_Notes-1.jpg">RedBoard ATmega328P Programmed with Arduino Connected to Qwiic Buzzers Daisy Chained and each playing a different tone</a></td>
      <td style="text-align: center; border: solid 1px #cccccc; vertical-align: middle;"><a href="../assets/img/24474-Daisy-Chaining-Qwiic-Buzzer-RedBoard_Arduino_Notes-2.jpg">RedBoard ATmega328P Programmed with Arduino Connected to Qwiic Buzzers Daisy Chained and each playing a different tone</a></td>
     </tr>
   </table>
 </div>

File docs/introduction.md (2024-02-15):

Beep-boop! The [SparkFun Qwiic Buzzer](https://www.sparkfun.com/products/24474) adds simple beeps and buzzes to your projects via I<sup>2</sup>C! Make some noises to alert you when something interesting (or terrible) happens. Simply connect a Qwiic cable and load up some pre-written code to an Arduino to start making noises! For those that want a simple buzz without an Arduino, you can also make noise by simply grounding the trigger pin!

<center>
<div class="grid cards" style="width:500px;" markdown>

-   <a href="https://www.sparkfun.com/products/24474">
      <figure markdown>
        SparkFun Qwiic Buzzer
      </figure>
    </a>

    ---

    <a href="https://www.sparkfun.com/products/24474">
      <b>SparkFun Qwiic Buzzer</b>
      <br />
      BOB-24474
      <br />
      <center>[Purchase from SparkFun :fontawesome-solid-cart-plus:](https://www.sparkfun.com/products/24474){ .md-button .md-button--primary }</center>
    </a>

</div>
</center>

<div style="text-align: center;">
  <iframe width="560" height="315" src="https://www.youtube.com/embed/ZPUQdX44Tsk?si=XaIp89KXAH5x2qBd" title="YouTube video player" frameborder="0" allow="accelerometer; autoplay; clipboard-write; encrypted-media; gyroscope; picture-in-picture; web-share" allowfullscreen></iframe>
</div>

In this tutorial, we'll go over the hardware and how to hookup the breakout board. We will also go over the examples to get started!

### Required Materials

To follow along with this tutorial, you will need the following materials. You may not need everything though depending on what you have. Add it to your cart, read through the guide, and adjust the cart as necessary.

* 1x [SparkFun RedBoard Plus [DEV-18158]](https://www.sparkfun.com/products/18158)
* 1x [Reversible USB A to C Cable - 0.8m [CAB-15425]](https://www.sparkfun.com/products/15425)
* 1x Qwiic Cable
    * [Flexible Qwiic Cable - 50mm [PRT-17260]](https://www.sparkfun.com/products/17260), for short distances
    * [Flexible Qwiic Cable - 500mm [PRT-17257]](https://www.sparkfun.com/products/17257), for those that need to wire the board farther away from your microcontroller
* [SparkFun Qwiic Buzzer [BOB-24474]](https://www.sparkfun.com/products/17257)

<div class="grid cards hide col-4" markdown>

<!-- ----------WHITE SPACE BETWEEN PRODUCTS---------- -->
-   <a href="https://www.sparkfun.com/products/18158">
      <figure markdown>
        SparkFun RedBoard Plus
      </figure>
    </a>

    ---

    <a href="https://www.sparkfun.com/products/18158">
      <b>SparkFun RedBoard Plus</b>
      <br />
      DEV-18158
    </a>
<!-- ----------WHITE SPACE BETWEEN PRODUCTS---------- -->
-   <a href="https://www.sparkfun.com/products/15425">
      <figure markdown>
        Reversible USB A to C Cable - 0.8m
      </figure>
    </a>

    ---

    <a href="https://www.sparkfun.com/products/15425">
      <b>Reversible USB A to C Cable - 0.8m</b>
      <br />
      CAB-15425
    </a>
<!-- ----------WHITE SPACE BETWEEN PRODUCTS---------- -->
-   <a href="https://www.sparkfun.com/products/17260">
      <figure markdown>
        Flexible Qwiic Cable - 50mm
      </figure>
    </a>

    ---

    <a href="https://www.sparkfun.com/products/17260">
      <b>Flexible Qwiic Cable - 50mm</b>
      <br>
      PRT-17260
    </a>
<!-- ----------WHITE SPACE BETWEEN PRODUCTS---------- -->
-   <a href="https://www.sparkfun.com/products/24474">
      <figure markdown>
        SparkFun Qwiic Buzzer
      </figure>
    </a>

    ---

    <a href="https://www.sparkfun.com/products/24474">
      <b>SparkFun Qwiic Buzzer</b>
      <br>
      BOB-24474
    </a>
<!-- ----------WHITE SPACE BETWEEN PRODUCTS---------- -->
</div>

### Tools &nbsp;_(Optional)_

You will need a soldering iron, solder, and [general soldering accessories](https://www.sparkfun.com/categories/49) for a secure connection when using the plated through holes.

<div class="grid cards hide col-4" markdown>

<!-- ----------WHITE SPACE BETWEEN PRODUCTS---------- -->
-   <a href="https://www.sparkfun.com/products/24063">
      <figure markdown>
        PINECIL Soldering Iron Kit
      </figure>
    </a>

    ---

    <a href="https://www.sparkfun.com/products/24063">
      <b>PINECIL Soldering Iron Kit</b>
      <br />
      KIT-24063
    </a>
<!-- ----------WHITE SPACE BETWEEN PRODUCTS---------- -->
-   <a href="https://www.sparkfun.com/products/9163">
      <figure markdown>
        Solder Lead Free - 15-gram Tube
      </figure>
    </a>

    ---

    <a href="https://www.sparkfun.com/products/9163">
      <b>Solder Lead Free - 15-gram Tube</b>
      <br>
      TOL-09163
    </a>
<!-- ----------WHITE SPACE BETWEEN PRODUCTS---------- -->
-   <a href="https://www.sparkfun.com/products/11375">
      <figure markdown>
        Hook-Up Wire - Assortment (Stranded, 22 AWG)
      </figure>
    </a>

    ---

    <a href="https://www.sparkfun.com/products/11375">
      <b>Hook-Up Wire - Assortment (Stranded, 22 AWG)</b>
      <br />
      PRT-11375
    </a>
<!-- ----------WHITE SPACE BETWEEN PRODUCTS---------- -->
-   <a href="https://www.sparkfun.com/products/22263">
      <figure markdown>
        Wire Stripper - 20-30 AWG Solid (22-32 AWG Stranded)
      </figure>
    </a>

    ---

    <a href="https://www.sparkfun.com/products/22263">
      <b>Wire Stripper - 20-30 AWG Solid (22-32 AWG Stranded)</b>
      <br />
      TOL-22263
    </a>
<!-- ----------WHITE SPACE BETWEEN PRODUCTS---------- -->
-   <a href="https://www.sparkfun.com/products/14782">
      <figure markdown>
        Flush Cutters - Xcelite
      </figure>
    </a>

    ---

    <a href="https://www.sparkfun.com/products/14782">
      <b>Flush Cutters - Xcelite</b>
      <br />
      TOL-14782
    </a>
<!-- ----------WHITE SPACE BETWEEN PRODUCTS---------- -->
</div>

### Prototyping Accessories &nbsp;_(Optional)_

For those connecting to the PTHs on the edge of the board or adding a custom resistor, you will need the following parts. You could use IC hooks for a temporary connection depending on your setup and what you have available. Of course, you will want to the solder header pins for a secure connection. Below are a few prototyping accessories that you may want to consider.

<div class="grid cards hide col-4" markdown>
<!-- ----------WHITE SPACE BETWEEN PRODUCTS---------- -->
-   <a href="https://www.sparkfun.com/products/12002">
      <figure markdown>
        Breadboard - Self-Adhesive (White)
      </figure>
    </a>

    ---

    <a href="https://www.sparkfun.com/products/12002">
      <b>Breadboard - Self-Adhesive (White)</b>
      <br />
      PRT-12002
    </a>
<!-- ----------WHITE SPACE BETWEEN PRODUCTS---------- -->
-   <a href="https://www.sparkfun.com/products/9741">
      <figure markdown>
        IC Hook with Pigtail
      </figure>
    </a>

    ---

    <a href="https://www.sparkfun.com/products/9741">
      <b>IC Hook with Pigtail</b>
      <br>
      CAB-09741
    </a>
<!-- ----------WHITE SPACE BETWEEN PRODUCTS---------- -->
-   <a href="https://www.sparkfun.com/products/116">
      <figure markdown>
        Break Away Headers - Straight
      </figure>
    </a>

    ---

    <a href="https://www.sparkfun.com/products/116">
      <b>Break Away Headers - Straight</b>
      <br />
      PRT-00116
    </a>
<!-- ----------WHITE SPACE BETWEEN PRODUCTS---------- -->
-   <a href="https://www.sparkfun.com/products/115">
      <figure markdown>
        Female Headers
      </figure>
    </a>

    ---

    <a href="https://www.sparkfun.com/products/115">
      <b>Female Headers</b>
      <br />
      PRT-00115
    </a>
<!-- ----------WHITE SPACE BETWEEN PRODUCTS---------- -->
-   <a href="https://www.sparkfun.com/products/8431">
      <figure markdown>
        Jumper Wires Premium 6
      <br />
      PRT-08431
    </a>
<!-- ----------WHITE SPACE BETWEEN PRODUCTS---------- -->
-   <a href="https://www.sparkfun.com/products/products/14460">
      <figure markdown>
        Multicolor Buttons - 4-pack
      </figure>
    </a>

    ---

    <a href="https://www.sparkfun.com/products/products/14460">
      <b>Multicolor Buttons - 4-pack</b>
      <br />
      PRT-14460
    </a>
<!-- ----------WHITE SPACE BETWEEN PRODUCTS---------- -->
-   <a href="https://www.sparkfun.com/products/products/10969">
      <figure markdown>
        Resistor Kit - 1/4W (500 total)
      </figure>
    </a>

    ---

    <a href="https://www.sparkfun.com/products/products/10969">
      <b>Resistor Kit - 1/4W (500 total)</b>
      <br />
      PRT-10969
    </a>
<!-- ----------WHITE SPACE BETWEEN PRODUCTS---------- -->
-   <a href="https://www.sparkfun.com/products/products/9806">
      <figure markdown>
        Resistor Kit - 1/4W (500 total)
      </figure>
    </a>

    ---

    <a href="https://www.sparkfun.com/products/products/9806">
      <b>Resistor Kit - 1/4W (500 total)</b>
      <br />
      COM-09806
    </a>
<!-- ----------WHITE SPACE BETWEEN PRODUCTS---------- -->
</div>

### Suggested Reading

If you aren't familiar with the Qwiic Connection System, we recommend reading [here for an overview](https://www.sparkfun.com/qwiic).

<div style="text-align: center">
  <table style="border-style:none">
    <tr>
     <td style="text-align: center; vertical-align: middle;">
     <div style="text-align: center"><a href="https://www.sparkfun.com/qwiic">Qwiic Connection System Click to learn more about the Qwiic Connection System!</a>
     </div>
    </td>
    </tr>
    <tr>
      <td style="text-align: center; vertical-align: middle;"><div style="text-align: center"><i><a href="https://www.sparkfun.com/qwiic">Qwiic Connection System</a></i></div></td>
    </tr>
  </table>
</div>

If you aren’t familiar with the following concepts, we also recommend checking out a few of these tutorials before continuing.

<div class="grid cards hide col-4" markdown>
<!-- ----------WHITE SPACE BETWEEN GRID CARDS---------- -->
-   <a href="https://learn.sparkfun.com/tutorials/i2c">
      <figure markdown>
        I2C
      </figure>
    </a>

    ---

    <a href="https://learn.sparkfun.com/tutorials/i2c">
      <b>I2C</b>
    </a>
<!-- ----------WHITE SPACE BETWEEN GRID CARDS---------- -->
-   <a href="https://learn.sparkfun.com/tutorials/redboard-plus-hookup-guide/all">
      <figure markdown>
        RedBoard Plus Hookup Guide
      </figure>
    </a>

    ---

    <a href="https://learn.sparkfun.com/tutorials/redboard-plus-hookup-guide/all">
      <b>RedBoard Plus Hookup Guide</b>
    </a>
<!-- ----------WHITE SPACE BETWEEN GRID CARDS---------- -->
-   <a href="https://learn.sparkfun.com/tutorials/installing-arduino-ide">
      <figure markdown>
        Installing Arduino IDE
      </figure>
    </a>

    ---

    <a href="https://learn.sparkfun.com/tutorials/installing-arduino-ide">
      <b>Installing Arduino IDE</b>
    </a>
<!-- ----------WHITE SPACE BETWEEN GRID CARDS---------- -->
-   <a href="https://learn.sparkfun.com/tutorials/installing-an-arduino-library">
      <figure markdown>
        Installing an Arduino Library
      </figure>
    </a>

    ---

    <a href="https://learn.sparkfun.com/tutorials/installing-an-arduino-library">
      <b>Installing an Arduino Library</b>
    </a>
<!-- ----------WHITE SPACE BETWEEN GRID CARDS---------- -->
</div>

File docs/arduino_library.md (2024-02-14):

!!! arduino
    This example assumes you are using the latest version of the Arduino IDE on your desktop. If this is your first time using the Arduino IDE, library, or board add-on, please review the following tutorials.

    - [Installing the Arduino IDE](https://learn.sparkfun.com/tutorials/installing-arduino-ide)
    - [Installing Board Definitions in the Arduino IDE](https://learn.sparkfun.com/tutorials/installing-board-definitions-in-the-arduino-ide)
    - [Installing an Arduino Library](https://learn.sparkfun.com/tutorials/installing-an-arduino-library)

!!! note
    If you've never connected an CH340 device to your computer before, you may need to install drivers for the USB-to-serial converter. Check out our section on "[How to Install CH340 Drivers](https://learn.sparkfun.com/tutorials/how-to-install-ch340-drivers)" for help with the installation.

SparkFun has written a library to work with the Qwiic Buzzer. You can obtain this library through the Arduino Library Manager by searching for "**SparkFun Qwiic Buzzer**". Find the one written by SparkFun Electronics and install the latest version. Users who prefer to manually install the library can get it from the [GitHub Repository](https://github.com/sparkfun/SparkFun_Qwiic_Buzzer_Arduino_Library) or download the .ZIP by clicking the button below:

<div style="text-align: center"><a href="https://github.com/sparkfun/SparkFun_Qwiic_Buzzer_Arduino_Library/archive/refs/heads/main.zip" class="md-button">SparkFun Qwiic Buzzer Arduino Library (ZIP)</a></div>

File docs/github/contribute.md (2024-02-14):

# Contribute: Help Fix our Mistake!
Spot something wrong? Feel free to contribute our open-source design and documentation. 

## Improve our Documentation
All of this documentation can be modified by you! Please help us make it better.

* These pages are contained in the [`docs` folder of the SparkFun Qwiic Buzzer repository](https://github.com/sparkfun/SparkFun_Qwiic_Buzzer/tree/main/docs).

### Submit a Correction
1. Fork this repo
2. Add your corrections or improvements to the markdown file
3. File a pull request with your changes, and enjoy making the ~~words~~ ~~worlds~~ world a better place.
    * Once received, the documentation specialist will automatically be notified.
    * We will review your suggested improvements to make sure they are correct and fit within our documentation standards.

## Improve our Hardware Design
All of our designs are open-source! Please help us make it better.

* Our board design files are contained in the [`Hardware` folder of the SparkFun Qwiic Buzzer repository](https://github.com/sparkfun/SparkFun_Qwiic_Buzzer/tree/main/Hardware).

### Submit a Design Improvement
1. Fork this repo
2. Add your design improvements
3. File a pull request with your changes, and enjoy making the ~~words~~ ~~worlds~~ world a better place.
    * Once received, the engineer in charge of the original design will automatically be notified.
    * We will review your suggested improvements, if they are within our board design standards and meet our product design requirements, we will flag these changes for our next board revision. *(Please note, that even if your suggestion is accepted, these changes may not be immediate. We may have to cycle through our current product inventory first.)*

## Contributors
Let's provided some recognition to the contributors for this project!

GitHub Contributors Image
<br>


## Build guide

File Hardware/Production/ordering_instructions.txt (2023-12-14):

panel size, 169x117mm
PCB thickness, 1.6mm
number of layers, 2
soldermask color, Red
silkscreen color, White
oz copper, 1oz
finish, HASL lead free
stencils, top
pcs per panel, 24
min trace width, 0.2032mm / 0.0080in
min drill size, 0.3810mm / 0.0150in

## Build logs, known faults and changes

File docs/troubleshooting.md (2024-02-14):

### General Troubleshooting Help

!!! note
    <span class="glyphicon glyphicon-question-sign" aria-hidden="true"></span>
        <strong> Not working as expected and need help? </strong> <br /><br />

    If you need technical assistance and more information on a product that is not working as you expected, we recommend heading on over to the <a href="https://www.sparkfun.com/technical_assistance">SparkFun Technical Assistance</a> page for some initial troubleshooting. <br /><br />

    <div style="text-align: center"><a href="https://www.sparkfun.com/technical_assistance" target="sfe_technical_assistance" class="md-button">SparkFun Technical Assistance Page</a></div>

    If you don't find what you need there, the <a href="https://forum.sparkfun.com/">SparkFun Forums</a> are a great place to find and ask for help. If this is your first visit, you'll need to <a href="https://forum.sparkfun.com/ucp.php?mode=register">create a Forum Account</a> to search product forums and post questions.<br /><br />

    <div style="text-align: center"><a href="https://forum.sparkfun.com/ucp.php?mode=register" class="md-button">Create New Forum Account</a>&nbsp;&nbsp;&nbsp;<a href="https://forum.sparkfun.com/viewforum.php?f=180" class="md-button md-button--primary">Log Into SparkFun Forums</a></div>

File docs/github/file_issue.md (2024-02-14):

# Did we make a mistake?

Spot something wrong? Please let us know. 

!!! attention
    This is not where customers should seek assistance on a product. If you require technical assistance or have questions about a product that is not working as expected, please head over to the [SparkFun Technical Assistance](https://www.sparkfun.com/technical_assistance) page for some initial troubleshooting.
    <center>
    [SparkFun Technical Assistance Page](https://www.sparkfun.com/technical_assistance){ .md-button .md-button--primary }
    </center>

    If you can't find what you need there, you'll need a [Forum Account](https://forum.sparkfun.com/ucp.php?mode=register) to search product forums and post questions.

## Discrepancies in the Documentation

All of this documentation can be modified by you! Please help us make it better.

* The documentation files for these pages are contained in the [`docs` folder of the SparkFun Qwiic Buzzer repository](https://github.com/sparkfun/SparkFun_Qwiic_Buzzer/tree/main/docs).

### Spot something wrong?
If a section of the documentation is incorrect, please [open an issue](https://github.com/sparkfun/SparkFun_Qwiic_Buzzer/issues) and let us know.

### Do you have a suggested correction?
1. With a GitHub account, fork this repo
2. Add your correction(s) or improvement(s) to the markdown file(s)
3. File a pull request with your changes, and enjoy making the ~~words~~ ~~worlds~~ world a better place.
    * Once received, the documentation specialist will automatically be notified.
    * We will review your suggested improvement(s) to make sure they are correct and fit within our documentation standards.

## Problems in the Hardware Design

All of our designs are open-source! Please help us make it better.

* Our board design files are contained in the [`Hardware` folder of the Qwiic Buzzer repository](https://github.com/sparkfun/SparkFun_Qwiic_Buzzer/tree/main/Hardware).

### Does something not make sense?
If part of the design is confusing, please [open an issue](https://github.com/sparkfun/SparkFun_Qwiic_Buzzer/issues) and let us know.

### Did we forget to include an important function of the board?
* Please keep in mind that we may intentionally exclude certain functions of the board to meet our product design requirements. *(For example, our Qwiic Micro boards are intended to fit on a small board layout and only use I<sup>2</sup>C communication; therefore, we may not have the SPI and interrupt pins available for users.)*
* If part of the board's functionality is missing, please [open an issue](https://github.com/sparkfun/SparkFun_Qwiic_Buzzer/issues) and file a feature request.

### Do you wish to contribute directly to improving the board design?
1. With a GitHub account, Fork this repo
2. Add your design improvement(s)
3. File a pull request with your changes, and enjoy making the ~~words~~ ~~worlds~~ world a better place.
    * Once received, the engineer in charge of the original design will automatically be notified.
    * We will review your suggested improvement(s), if they are within our board design standards and meet our product design requirements, we will flag these changes for our next board revision. *(Please note, that even if your suggestion is accepted, these changes may not be immediate. We may have to cycle through our current product inventory first.)*

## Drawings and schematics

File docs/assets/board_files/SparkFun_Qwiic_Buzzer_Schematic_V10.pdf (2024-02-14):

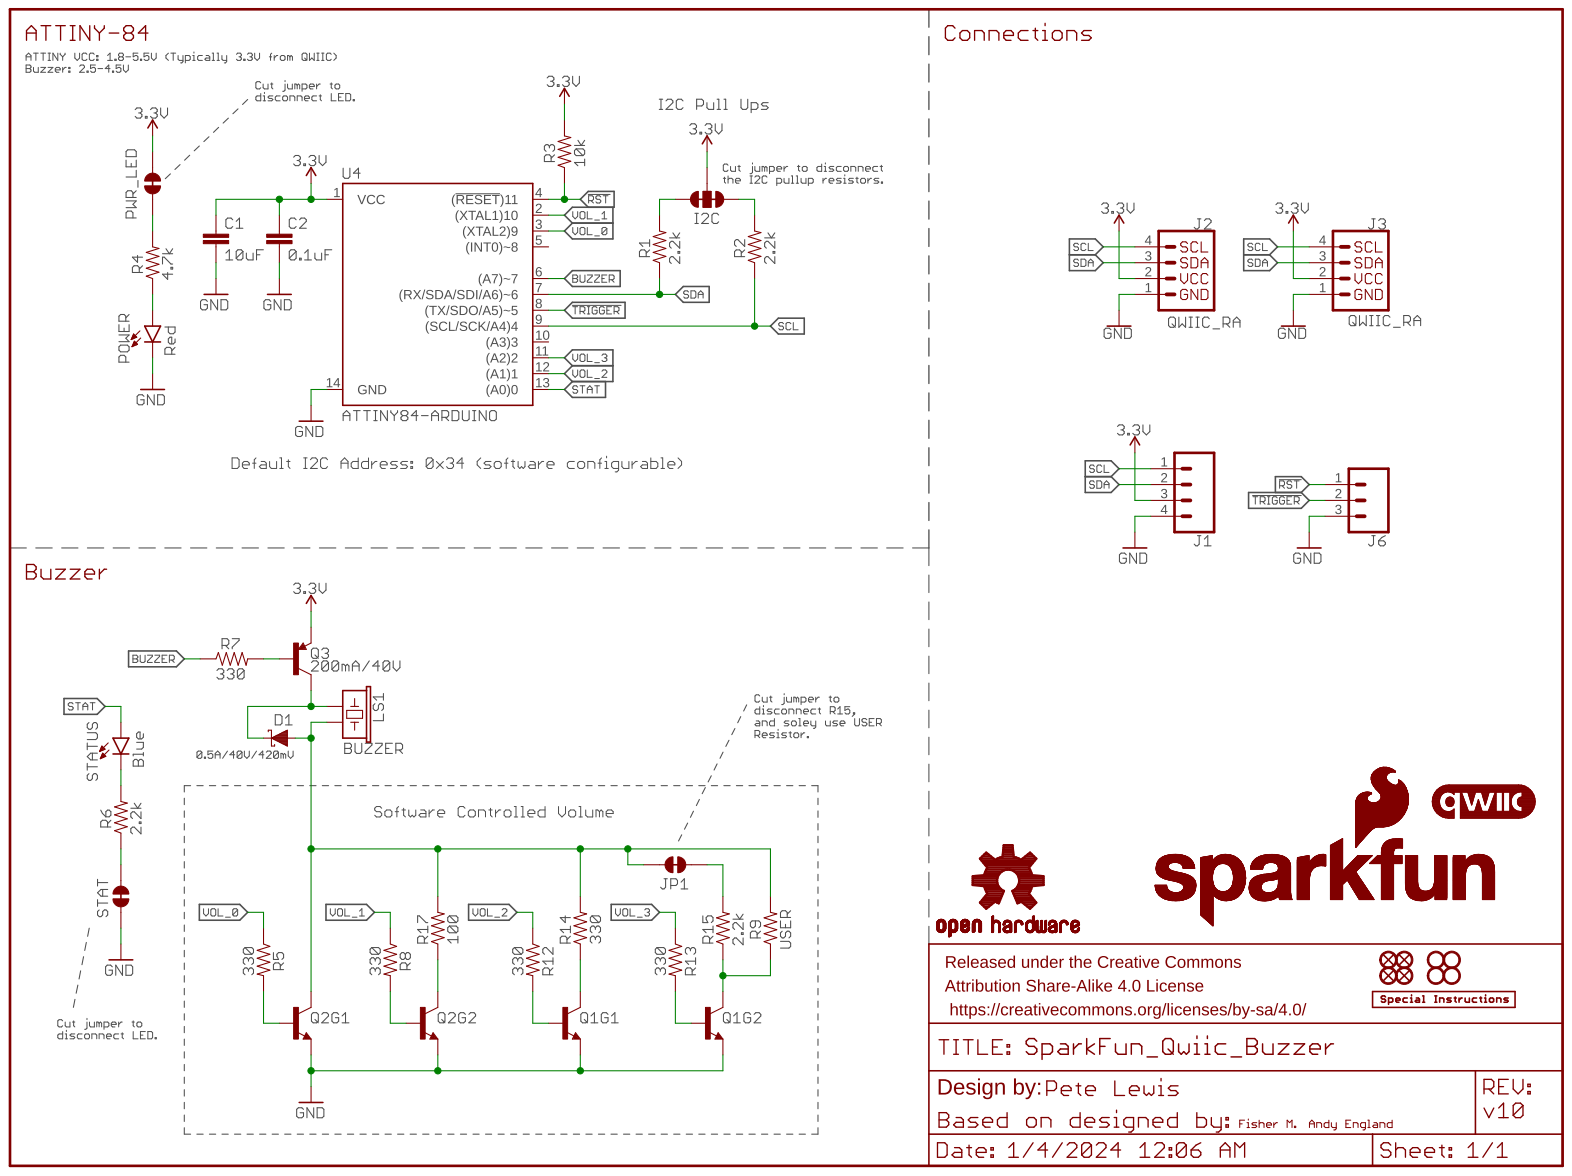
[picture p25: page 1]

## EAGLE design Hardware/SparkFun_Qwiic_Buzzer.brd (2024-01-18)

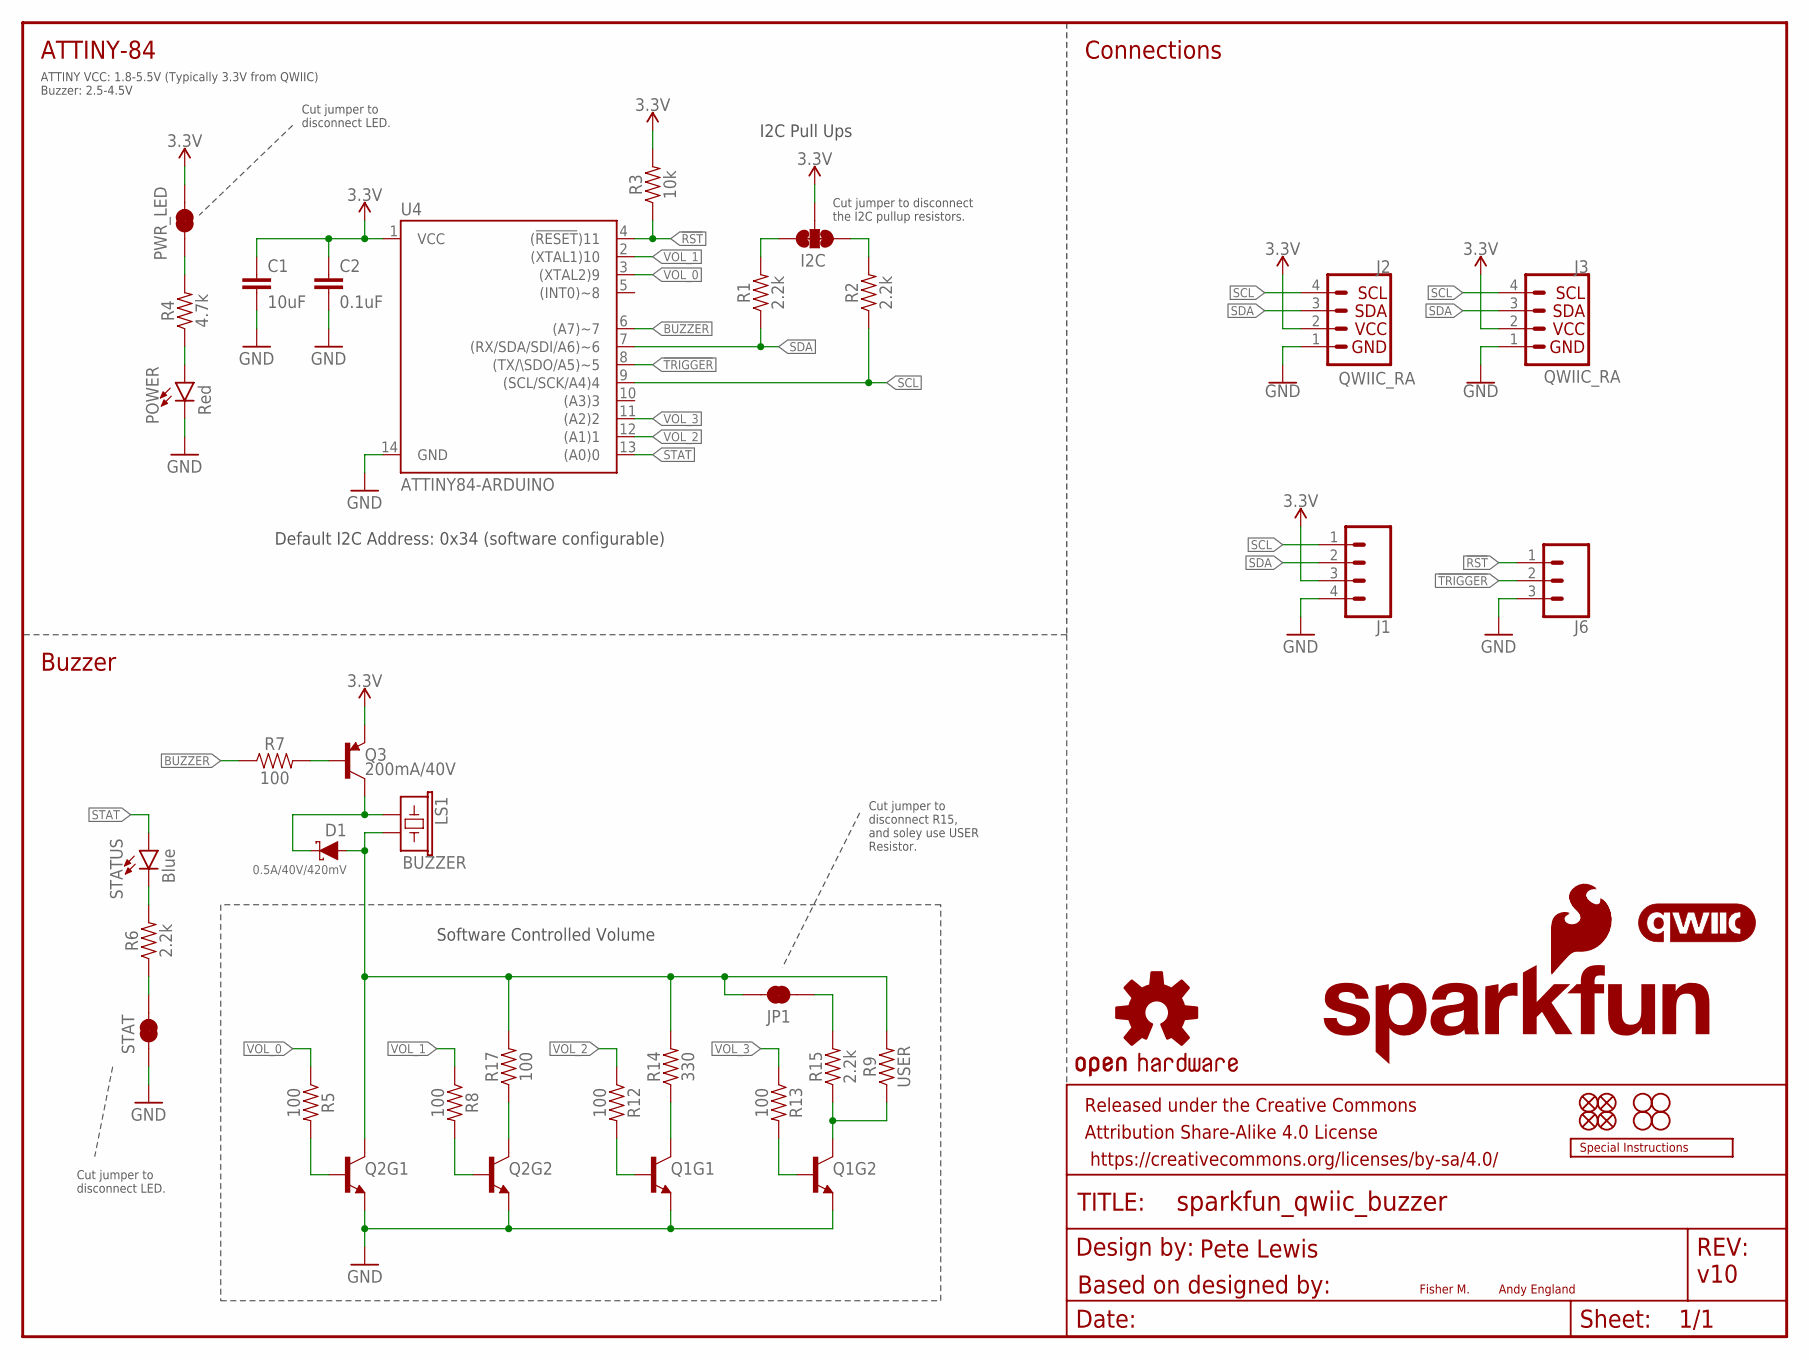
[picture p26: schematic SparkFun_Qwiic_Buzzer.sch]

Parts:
C1: 10uF; 0402-TIGHT
C2: 0.1uF; 0402-TIGHT
D1: 0.5A/40V/420mV; SOD-323
FRAME1: FRAME-LETTER; CREATIVE_COMMONS
H1, H2, H3, H4: STAND-OFF
I2C: JUMPER-SMT_3_2-NC_TRACE_SILK; SMT-JUMPER_3_2-NC_TRACE_SILK
J1: CONN_041X04_NO_SILK; 1X04_NO_SILK
J2, J3: QWIIC_RA; JST04_1MM_RA
J6: CONN_031X03_NO_SILK; 1X03_NO_SILK
JP1: JUMPER-SMT_2_NC_TRACE_SILK; SMT-JUMPER_2_NC_TRACE_SILK
JP2, JP6, JP8, JP9: FIDUCIALUFIDUCIAL; FIDUCIAL-MICRO
LOGO1: OSHW-LOGOMINI; OSHW-LOGO-MINI
LOGO2: SFE_LOGO_NAME_FLAME.1_INCH; SFE_LOGO_NAME_FLAME_.1
LOGO3: SPECIAL_INSTRUCTIONS-ORDERING; ORDERING_INSTRUCTIONS
LOGO4: SFE_LOGO_FLAME.1_INCH; SFE_LOGO_FLAME_.1
LOGO5: QWIIC_LOGO_4MM; QWIIC_4MM
LS1: BUZZER; BUZZER-CCV
POWER: Red; LED-0603
PWR_LED: PWR_LED; SMT-JUMPER_2_NC_TRACE_SILK
Q1, Q2: TRANS_NPN_DUAL-MBT3904DW1T1; SC70-6
Q3: 200mA/40V; SOT23-3
R1, R2, R6, R15: 2.2k; 0402-TIGHT
R3: 10k; 0402-TIGHT
R4: 4.7k; 0402-TIGHT
R5, R7, R8, R12, R13, R17: 100; 0402-TIGHT
R9: USER; AXIAL-0.3
R14: 330; 0402-TIGHT
STAT: PWR_LED; SMT-JUMPER_2_NC_TRACE_SILK
STATUS: Blue; LED-0603
U4: ATTINY84-ARDUINO; SO14

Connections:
3.3V: C1.1, C2.1, I2C.2, J1.3, J2.2, J3.2, PWR_LED.2, Q3.2 (E), R3.2, U4.1 (VCC)
!RST: J6.1, R3.1, U4.4 ((!RESET!)11)
!TRIGGER!: J6.2, U4.8 ((TX/\SDO/A5)~5)
BUZZER: R7.1, U4.6 ((A7)~7)
GND: C1.2, C2.2, J1.4, J2.1, J3.1, J6.3, POWER.C, Q1.1 (E), Q1.4 (E), Q2.1 (E), Q2.4 (E), STAT.1, U4.14 (GND)
unnamed: PWR_LED.1, R4.2
unnamed: Q2.5 (B), R5.2
unnamed: POWER.A, R4.1
unnamed: D1.A, JP1.2, LS1.- (2), Q2.3 (C), R9.P$2 (2), R14.2, R17.2
unnamed: Q3.1 (B), R7.2
unnamed: D1.C, LS1.+ (1), Q3.3 (C)
unnamed: R6.2, STATUS.C
unnamed: R6.1, STAT.2
unnamed: Q1.2 (B), R13.2
unnamed: Q1.5 (B), R12.2
unnamed: Q2.2 (B), R8.2
unnamed: Q2.6 (C), R17.1
unnamed: Q1.3 (C), R14.1
unnamed: Q1.6 (C), R9.P$1 (1), R15.1
unnamed: JP1.1, R15.2
SCL: J1.1, J2.4, J3.4, R2.1, U4.9 ((SCL/SCK/A4)4)
SCL_PU1: I2C.1, R2.2
SDA: J1.2, J2.3, J3.3, R1.1, U4.7 ((RX/SDA/SDI/A6)~6)
SDA_PU1: I2C.3, R1.2
STAT: STATUS.A, U4.13 ((A0)0)
VOL_0: R5.1, U4.3 ((XTAL2)9)
VOL_1: R8.1, U4.2 ((XTAL1)10)
VOL_2: R12.1, U4.12 ((A1)1)
VOL_3: R13.1, U4.11 ((A2)2)

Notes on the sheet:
v10
Connections
Cut jumper to disconnect the I2C pullup resistors.
I2C Pull Ups
Fisher M.
Andy England
ATTINY-84
Buzzer
ATTINY VCC: 1.8-5.5V (Typically 3.3V from QWIIC) Buzzer: 2.5-4.5V
Based on designed by:
Pete Lewis
Software Controlled Volume
Cut jumper to disconnect LED.
Default I2C Address: 0x34 (software configurable)
Cut jumper to disconnect R15, and soley use USER Resistor.

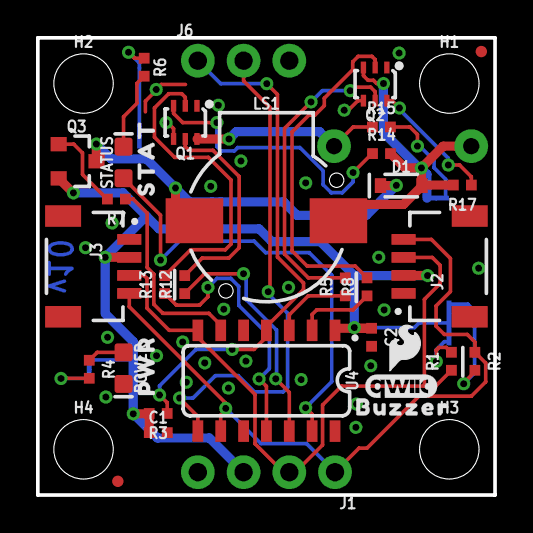
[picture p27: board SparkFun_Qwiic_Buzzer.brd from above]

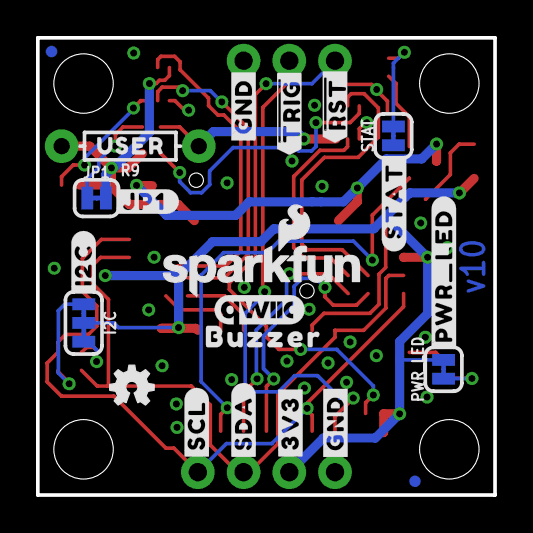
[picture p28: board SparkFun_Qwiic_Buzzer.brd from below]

Board: 2 copper layers, 25.4 x 25.4 mm, 63 parts (23 on the bottom side), 29 nets.

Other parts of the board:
U$1: STAT0
U$2, U$10: #GND#0
U$5: #PWR_LED#13
U$6: #JP1#14
U$7: #STAT#3
U$8: USER12
U$9: PWR0
U$11: #I2C#0
U$12: ##RST##7
U$13: BUZZER1
U$15: ##TRIG##6
U$16: QWIIC_5MM
U$17: #3V3#0
U$18: #SCL#0
U$19: #SDA#0
U$22: BUZZER14

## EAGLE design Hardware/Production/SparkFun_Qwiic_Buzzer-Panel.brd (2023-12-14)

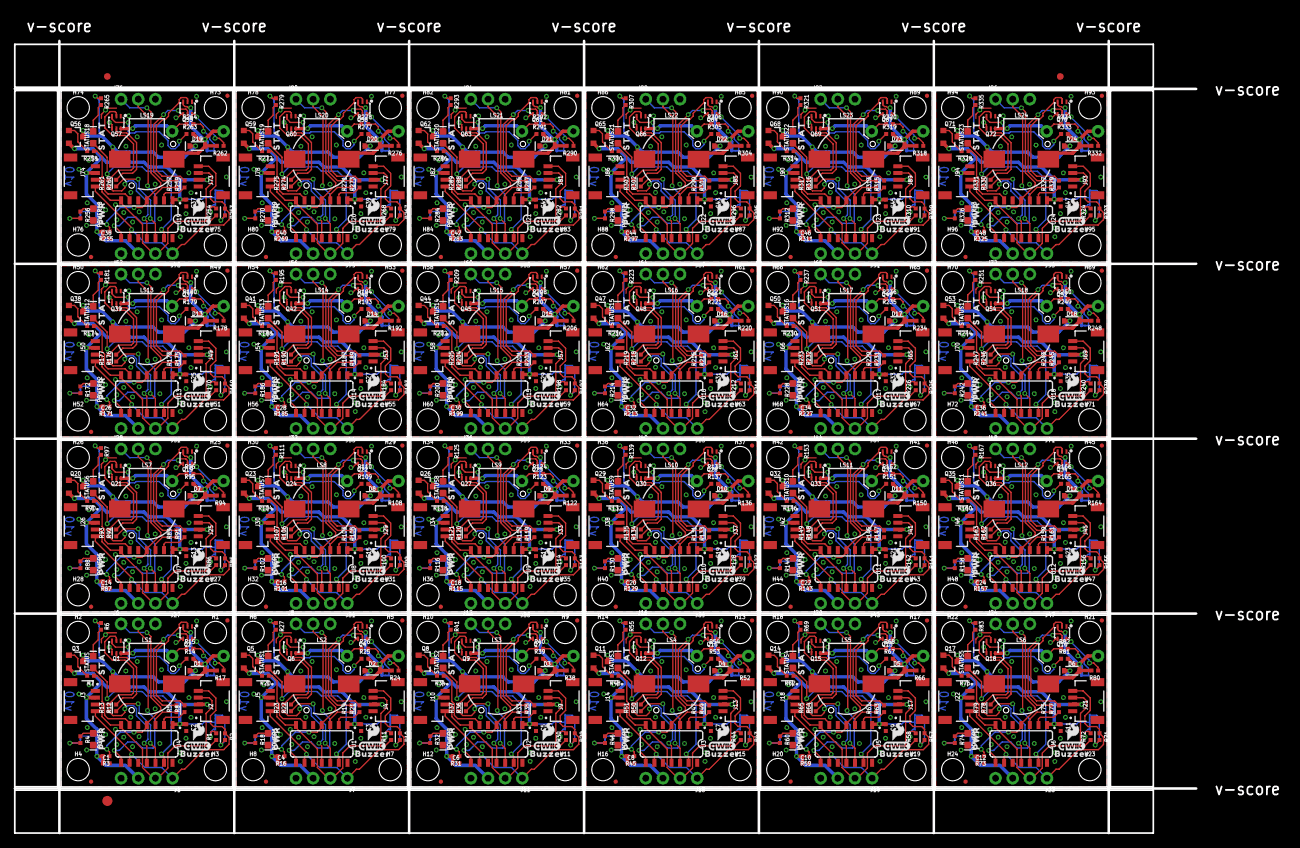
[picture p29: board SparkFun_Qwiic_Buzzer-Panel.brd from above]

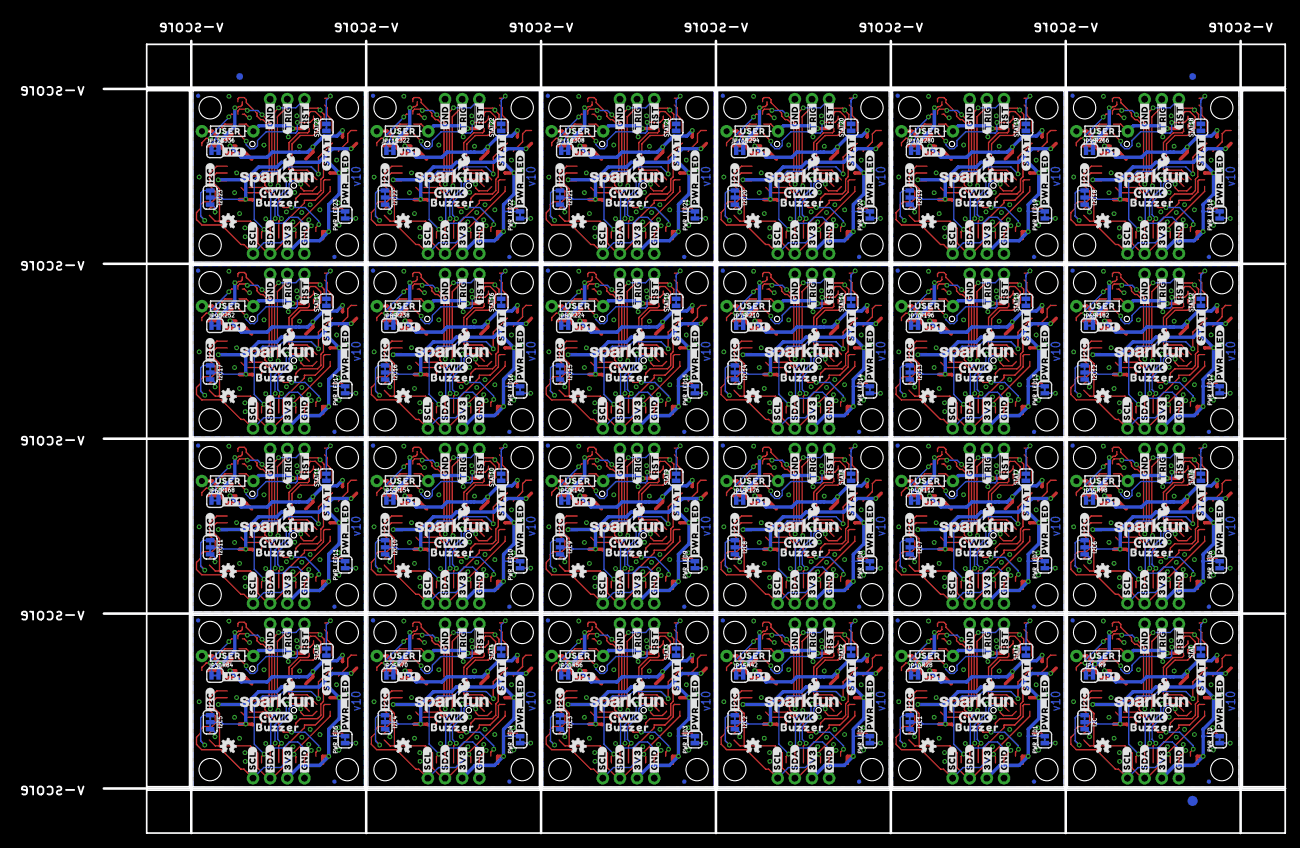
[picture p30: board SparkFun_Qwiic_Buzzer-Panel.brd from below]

Board: 2 copper layers, 175.0 x 117.3 mm, 1470 parts (555 on the bottom side), 696 nets.

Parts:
C1, C4, C6, C8, C10, C12, C14, C16, C18, C20, C22, C24, C26, C28, C30, C32, C34, C36, C38, C40, C42, C44, C46, C48: 10uF; 0402-TIGHT
C2, C3, C5, C7, C9, C11, C13, C15, C17, C19, C21, C23, C25, C27, C29, C31, C33, C35, C37, C39, C41, C43, C45, C47: 0.1uF; 0402-TIGHT
D1, D2, D3, D4, D5, D6, D7, D8, D9, D10, D11, D12, D13, D14, D15, D16, D17, D18, D19, D20, D21, D22, D23, D24: 0.5A/40V/420mV; SOD-323
E$1, E$2, E$3, E$4: FIDUCIAL-1X2
E$5, E$6: FIDUCIAL-1.5X3
H1, H2, H3, H4, H5, H6, H7, H8, H9, H10, H11, H12, H13, H14, H15, H16, H17, H18, H19, H20, H21, H22, H23, H24, H25, H26, H27, H28, H29, H30, H31, H32, H33, H34, H35, H36, H37, H38, H39, H40, H41, H42, H43, H44, H45, H46, H47, H48, H49, H50, H51, H52, H53, H54, H55, H56, H57, H58, H59, H60, H61, H62, H63, H64, H65, H66, H67, H68, H69, H70, H71, H72, H73, H74, H75, H76, H77, H78, H79, H80, H81, H82, H83, H84, H85, H86, H87, H88, H89, H90, H91, H92, H93, H94, H95, H96: STAND-OFF
I2C, I2C1, I2C2, I2C3, I2C4, I2C5, I2C6, I2C7, I2C8, I2C9, I2C10, I2C11, I2C12, I2C13, I2C14, I2C15, I2C16, I2C17, I2C18, I2C19, I2C20, I2C21, I2C22, I2C23: JUMPER-SMT_3_2-NC_TRACE_SILK; SMT-JUMPER_3_2-NC_TRACE_SILK
J1, J7, J11, J15, J19, J23, J27, J31, J35, J39, J43, J47, J51, J55, J59, J63, J67, J71, J75, J79, J83, J87, J91, J95: 1X04_NO_SILK
J2, J3, J4, J5, J9, J10, J13, J14, J17, J18, J21, J22, J25, J26, J29, J30, J33, J34, J37, J38, J41, J42, J45, J46, J49, J50, J53, J54, J57, J58, J61, J62, J65, J66, J69, J70, J73, J74, J77, J78, J81, J82, J85, J86, J89, J90, J93, J94: QWIIC_RA; JST04_1MM_RA
J6, J8, J12, J16, J20, J24, J28, J32, J36, J40, J44, J48, J52, J56, J60, J64, J68, J72, J76, J80, J84, J88, J92, J96: 1X03_NO_SILK
JP1, JP10, JP15, JP20, JP25, JP30, JP35, JP40, JP45, JP50, JP55, JP60, JP65, JP70, JP75, JP80, JP85, JP90, JP95, JP100, JP105, JP110, JP115, JP120: SMT-JUMPER_2_NC_TRACE_SILK
JP2, JP3, JP4, JP5, JP6, JP7, JP8, JP9, JP11, JP12, JP13, JP14, JP16, JP17, JP18, JP19, JP21, JP22, JP23, JP24, JP26, JP27, JP28, JP29, JP31, JP32, JP33, JP34, JP36, JP37, JP38, JP39, JP41, JP42, JP43, JP44, JP46, JP47, JP48, JP49, JP51, JP52, JP53, JP54, JP56, JP57, JP58, JP59, JP61, JP62, JP63, JP64, JP66, JP67, JP68, JP69, JP71, JP72, JP73, JP74, JP76, JP77, JP78, JP79, JP81, JP82, JP83, JP84, JP86, JP87, JP88, JP89, JP91, JP92, JP93, JP94, JP96, JP97, JP98, JP99, JP101, JP102, JP103, JP104, JP106, JP107, JP108, JP109, JP111, JP112, JP113, JP114, JP116, JP117, JP118, JP119: FIDUCIALUFIDUCIAL; FIDUCIAL-MICRO
LOGO1, LOGO3, LOGO9, LOGO13, LOGO17, LOGO21, LOGO25, LOGO29, LOGO33, LOGO37, LOGO41, LOGO45, LOGO49, LOGO53, LOGO57, LOGO61, LOGO65, LOGO69, LOGO73, LOGO77, LOGO81, LOGO85, LOGO89, LOGO93: OSHW-LOGOMINI; OSHW-LOGO-MINI
LOGO2, LOGO7, LOGO11, LOGO15, LOGO19, LOGO23, LOGO27, LOGO31, LOGO35, LOGO39, LOGO43, LOGO47, LOGO51, LOGO55, LOGO59, LOGO63, LOGO67, LOGO71, LOGO75, LOGO79, LOGO83, LOGO87, LOGO91, LOGO95: SFE_LOGO_NAME_FLAME.1_INCH; SFE_LOGO_NAME_FLAME_.1
LOGO4, LOGO6, LOGO10, LOGO14, LOGO18, LOGO22, LOGO26, LOGO30, LOGO34, LOGO38, LOGO42, LOGO46, LOGO50, LOGO54, LOGO58, LOGO62, LOGO66, LOGO70, LOGO74, LOGO78, LOGO82, LOGO86, LOGO90, LOGO94: SFE_LOGO_FLAME.1_INCH; SFE_LOGO_FLAME_.1
LOGO5, LOGO8, LOGO12, LOGO16, LOGO20, LOGO24, LOGO28, LOGO32, LOGO36, LOGO40, LOGO44, LOGO48, LOGO52, LOGO56, LOGO60, LOGO64, LOGO68, LOGO72, LOGO76, LOGO80, LOGO84, LOGO88, LOGO92, LOGO96: QWIIC_LOGO_4MM; QWIIC_4MM
LS1, LS2, LS3, LS4, LS5, LS6, LS7, LS8, LS9, LS10, LS11, LS12, LS13, LS14, LS15, LS16, LS17, LS18, LS19, LS20, LS21, LS22, LS23, LS24: BUZZER; BUZZER-CCV
POWER, POWER1, POWER2, POWER3, POWER4, POWER5, POWER6, POWER7, POWER8, POWER9, POWER10, POWER11, POWER12, POWER13, POWER14, POWER15, POWER16, POWER17, POWER18, POWER19, POWER20, POWER21, POWER22, POWER23: Red; LED-0603
PWR_LED, PWR_LED1, PWR_LED2, PWR_LED3, PWR_LED4, PWR_LED5, PWR_LED6, PWR_LED7, PWR_LED8, PWR_LED9, PWR_LED10, PWR_LED11, PWR_LED12, PWR_LED13, PWR_LED14, PWR_LED15, PWR_LED16, PWR_LED17, PWR_LED18, PWR_LED19, PWR_LED20, PWR_LED21, PWR_LED22, PWR_LED23: PWR_LED; SMT-JUMPER_2_NC_TRACE_SILK
Q1, Q2, Q4, Q6, Q7, Q9, Q10, Q12, Q13, Q15, Q16, Q18, Q19, Q21, Q22, Q24, Q25, Q27, Q28, Q30, Q31, Q33, Q34, Q36, Q37, Q39, Q40, Q42, Q43, Q45, Q46, Q48, Q49, Q51, Q52, Q54, Q55, Q57, Q58, Q60, Q61, Q63, Q64, Q66, Q67, Q69, Q70, Q72: SC70-6
Q3, Q5, Q8, Q11, Q14, Q17, Q20, Q23, Q26, Q29, Q32, Q35, Q38, Q41, Q44, Q47, Q50, Q53, Q56, Q59, Q62, Q65, Q68, Q71: 200mA/40V; SOT23-3
R1, R2, R6, R10, R11, R15, R26, R27, R29, R30, R40, R41, R43, R44, R54, R55, R57, R58, R68, R69, R71, R72, R82, R83, R85, R86, R96, R97, R99, R100, R110, R111, R113, R114, R124, R125, R127, R128, R138, R139, R141, R142, R152, R153, R155, R156, R166, R167, R169, R170, R180, R181, R183, R184, R194, R195, R197, R198, R208, R209, R211, R212, R222, R223, R225, R226, R236, R237, R239, R240, R250, R251, R253, R254, R264, R265, R267, R268, R278, R279, R281, R282, R292, R293, R295, R296, R306, R307, R309, R310, R320, R321, R323, R324, R334, R335: 2.2k; 0402-TIGHT
R3, R16, R31, R45, R59, R73, R87, R101, R115, R129, R143, R157, R171, R185, R199, R213, R227, R241, R255, R269, R283, R297, R311, R325: 10k; 0402-TIGHT
R4, R18, R32, R46, R60, R74, R88, R102, R116, R130, R144, R158, R172, R186, R200, R214, R228, R242, R256, R270, R284, R298, R312, R326: 4.7k; 0402-TIGHT
R5, R7, R8, R12, R13, R14, R19, R20, R21, R22, R23, R25, R33, R34, R35, R36, R37, R39, R47, R48, R49, R50, R51, R53, R61, R62, R63, R64, R65, R67, R75, R76, R77, R78, R79, R81, R89, R90, R91, R92, R93, R95, R103, R104, R105, R106, R107, R109, R117, R118, R119, R120, R121, R123, R131, R132, R133, R134, R135, R137, R145, R146, R147, R148, R149, R151, R159, R160, R161, R162, R163, R165, R173, R174, R175, R176, R177, R179, R187, R188, R189, R190, R191, R193, R201, R202, R203, R204, R205, R207, R215, R216, R217, R218, R219, R221, R229, R230, R231, R232, R233, R235, R243, R244, R245, R246, R247, R249, R257, R258, R259, R260, R261, R263, R271, R272, R273, R274, R275, R277, R285, R286, R287, R288, R289, R291, R299, R300, R301, R302, R303, R305, R313, R314, R315, R316, R317, R319, R327, R328, R329, R330, R331, R333: 330; 0402-TIGHT
R9, R28, R42, R56, R70, R84, R98, R112, R126, R140, R154, R168, R182, R196, R210, R224, R238, R252, R266, R280, R294, R308, R322, R336: USER; AXIAL-0.3
R17, R24, R38, R52, R66, R80, R94, R108, R122, R136, R150, R164, R178, R192, R206, R220, R234, R248, R262, R276, R290, R304, R318, R332: 100; 0402-TIGHT
STAT, STAT1, STAT2, STAT3, STAT4, STAT5, STAT6, STAT7, STAT8, STAT9, STAT10, STAT11, STAT12, STAT13, STAT14, STAT15, STAT16, STAT17, STAT18, STAT19, STAT20, STAT21, STAT22, STAT23: PWR_LED; SMT-JUMPER_2_NC_TRACE_SILK
STATUS, STATUS1, STATUS2, STATUS3, STATUS4, STATUS5, STATUS6, STATUS7, STATUS8, STATUS9, STATUS10, STATUS11, STATUS12, STATUS13, STATUS14, STATUS15, STATUS16, STATUS17, STATUS18, STATUS19, STATUS20, STATUS21, STATUS22, STATUS23: Blue; LED-0603
U1, U2, U3, U4, U5, U6, U7, U8, U9, U10, U11, U12, U13, U14, U15, U16, U17, U18, U19, U20, U21, U22, U23, U24: ATTINY84-ARDUINO; SO14
U$1, U$3, U$35, U$52, U$69, U$86, U$103, U$120, U$137, U$154, U$171, U$188, U$205, U$222, U$239, U$256, U$273, U$290, U$307, U$324, U$341, U$358, U$375, U$392: STAT0
U$2, U$10, U$23, U$24, U$40, U$41, U$57, U$58, U$74, U$75, U$91, U$92, U$108, U$109, U$125, U$126, U$142, U$143, U$159, U$160, U$176, U$177, U$193, U$194, U$210, U$211, U$227, U$228, U$244, U$245, U$261, U$262, U$278, U$279, U$295, U$296, U$312, U$313, U$329, U$330, U$346, U$347, U$363, U$364, U$380, U$381, U$397, U$398: #GND#0
U$4, U$9, U$36, U$53, U$70, U$87, U$104, U$121, U$138, U$155, U$172, U$189, U$206, U$223, U$240, U$257, U$274, U$291, U$308, U$325, U$342, U$359, U$376, U$393: PWR0
U$5, U$32, U$49, U$66, U$83, U$100, U$117, U$134, U$151, U$168, U$185, U$202, U$219, U$236, U$253, U$270, U$287, U$304, U$321, U$338, U$355, U$372, U$389, U$406: #PWR_LED#13
U$6, U$33, U$50, U$67, U$84, U$101, U$118, U$135, U$152, U$169, U$186, U$203, U$220, U$237, U$254, U$271, U$288, U$305, U$322, U$339, U$356, U$373, U$390, U$407: #JP1#14
U$7, U$28, U$45, U$62, U$79, U$96, U$113, U$130, U$147, U$164, U$181, U$198, U$215, U$232, U$249, U$266, U$283, U$300, U$317, U$334, U$351, U$368, U$385, U$402: #STAT#3
U$8, U$31, U$48, U$65, U$82, U$99, U$116, U$133, U$150, U$167, U$184, U$201, U$218, U$235, U$252, U$269, U$286, U$303, U$320, U$337, U$354, U$371, U$388, U$405: USER12
U$11, U$21, U$39, U$56, U$73, U$90, U$107, U$124, U$141, U$158, U$175, U$192, U$209, U$226, U$243, U$260, U$277, U$294, U$311, U$328, U$345, U$362, U$379, U$396: #I2C#0
U$12, U$29, U$46, U$63, U$80, U$97, U$114, U$131, U$148, U$165, U$182, U$199, U$216, U$233, U$250, U$267, U$284, U$301, U$318, U$335, U$352, U$369, U$386, U$403: ##RST##7
U$13, U$20, U$38, U$55, U$72, U$89, U$106, U$123, U$140, U$157, U$174, U$191, U$208, U$225, U$242, U$259, U$276, U$293, U$310, U$327, U$344, U$361, U$378, U$395: BUZZER1
U$14, U$16, U$37, U$54, U$71, U$88, U$105, U$122, U$139, U$156, U$173, U$190, U$207, U$224, U$241, U$258, U$275, U$292, U$309, U$326, U$343, U$360, U$377, U$394: QWIIC_5MM
U$15, U$30, U$47, U$64, U$81, U$98, U$115, U$132, U$149, U$166, U$183, U$200, U$217, U$234, U$251, U$268, U$285, U$302, U$319, U$336, U$353, U$370, U$387, U$404: ##TRIG##6
U$17, U$25, U$42, U$59, U$76, U$93, U$110, U$127, U$144, U$161, U$178, U$195, U$212, U$229, U$246, U$263, U$280, U$297, U$314, U$331, U$348, U$365, U$382, U$399: #3V3#0
U$18, U$27, U$44, U$61, U$78, U$95, U$112, U$129, U$146, U$163, U$180, U$197, U$214, U$231, U$248, U$265, U$282, U$299, U$316, U$333, U$350, U$367, U$384, U$401: #SCL#0
U$19, U$26, U$43, U$60, U$77, U$94, U$111, U$128, U$145, U$162, U$179, U$196, U$213, U$230, U$247, U$264, U$281, U$298, U$315, U$332, U$349, U$366, U$383, U$400: #SDA#0
U$22, U$34, U$51, U$68, U$85, U$102, U$119, U$136, U$153, U$170, U$187, U$204, U$221, U$238, U$255, U$272, U$289, U$306, U$323, U$340, U$357, U$374, U$391, U$408: BUZZER14

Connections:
3.3V: C1.1, C2.1, I2C.2, J1.3, J2.2, J3.2, PWR_LED.2, Q3.2, R3.2, U4.1
3.3V1: C3.1, C4.1, I2C1.2, J4.2, J5.2, J7.3, PWR_LED1.2, Q5.2, R16.2, U1.1
3.3V2: C5.1, C6.1, I2C2.2, J9.2, J10.2, J11.3, PWR_LED2.2, Q8.2, R31.2, U2.1
3.3V3: C7.1, C8.1, I2C3.2, J13.2, J14.2, J15.3, PWR_LED3.2, Q11.2, R45.2, U3.1
3.3V4: C9.1, C10.1, I2C4.2, J17.2, J18.2, J19.3, PWR_LED4.2, Q14.2, R59.2, U5.1
3.3V5: C11.1, C12.1, I2C5.2, J21.2, J22.2, J23.3, PWR_LED5.2, Q17.2, R73.2, U6.1
3.3V6: C13.1, C14.1, I2C6.2, J25.2, J26.2, J27.3, PWR_LED6.2, Q20.2, R87.2, U7.1
3.3V7: C15.1, C16.1, I2C7.2, J29.2, J30.2, J31.3, PWR_LED7.2, Q23.2, R101.2, U8.1
3.3V8: C17.1, C18.1, I2C8.2, J33.2, J34.2, J35.3, PWR_LED8.2, Q26.2, R115.2, U9.1
3.3V9: C19.1, C20.1, I2C9.2, J37.2, J38.2, J39.3, PWR_LED9.2, Q29.2, R129.2, U10.1
3.3V10: C21.1, C22.1, I2C10.2, J41.2, J42.2, J43.3, PWR_LED10.2, Q32.2, R143.2, U11.1
3.3V11: C23.1, C24.1, I2C11.2, J45.2, J46.2, J47.3, PWR_LED11.2, Q35.2, R157.2, U12.1
3.3V12: C25.1, C26.1, I2C12.2, J49.2, J50.2, J51.3, PWR_LED12.2, Q38.2, R171.2, U13.1
3.3V13: C27.1, C28.1, I2C13.2, J53.2, J54.2, J55.3, PWR_LED13.2, Q41.2, R185.2, U14.1
3.3V14: C29.1, C30.1, I2C14.2, J57.2, J58.2, J59.3, PWR_LED14.2, Q44.2, R199.2, U15.1
3.3V15: C31.1, C32.1, I2C15.2, J61.2, J62.2, J63.3, PWR_LED15.2, Q47.2, R213.2, U16.1
3.3V16: C33.1, C34.1, I2C16.2, J65.2, J66.2, J67.3, PWR_LED16.2, Q50.2, R227.2, U17.1
3.3V17: C35.1, C36.1, I2C17.2, J69.2, J70.2, J71.3, PWR_LED17.2, Q53.2, R241.2, U18.1
3.3V18: C37.1, C38.1, I2C18.2, J73.2, J74.2, J75.3, PWR_LED18.2, Q56.2, R255.2, U19.1
3.3V19: C39.1, C40.1, I2C19.2, J77.2, J78.2, J79.3, PWR_LED19.2, Q59.2, R269.2, U20.1
3.3V20: C41.1, C42.1, I2C20.2, J81.2, J82.2, J83.3, PWR_LED20.2, Q62.2, R283.2, U21.1
3.3V21: C43.1, C44.1, I2C21.2, J85.2, J86.2, J87.3, PWR_LED21.2, Q65.2, R297.2, U22.1
3.3V22: C45.1, C46.1, I2C22.2, J89.2, J90.2, J91.3, PWR_LED22.2, Q68.2, R311.2, U23.1
3.3V23: C47.1, C48.1, I2C23.2, J93.2, J94.2, J95.3, PWR_LED23.2, Q71.2, R325.2, U24.1
!RST: J6.1, R3.1, U4.4
!RST1: J8.1, R16.1, U1.4
!RST2: J12.1, R31.1, U2.4
!RST3: J16.1, R45.1, U3.4
!RST4: J20.1, R59.1, U5.4
!RST5: J24.1, R73.1, U6.4
!RST6: J28.1, R87.1, U7.4
!RST7: J32.1, R101.1, U8.4
!RST8: J36.1, R115.1, U9.4
!RST9: J40.1, R129.1, U10.4
!RST10: J44.1, R143.1, U11.4
!RST11: J48.1, R157.1, U12.4
!RST12: J52.1, R171.1, U13.4
!RST13: J56.1, R185.1, U14.4
!RST14: J60.1, R199.1, U15.4
!RST15: J64.1, R213.1, U16.4
!RST16: J68.1, R227.1, U17.4
!RST17: J72.1, R241.1, U18.4
!RST18: J76.1, R255.1, U19.4
!RST19: J80.1, R269.1, U20.4
!RST20: J84.1, R283.1, U21.4
!RST21: J88.1, R297.1, U22.4
!RST22: J92.1, R311.1, U23.4
!RST23: J96.1, R325.1, U24.4
!TRIGGER!: J6.2, U4.8
!TRIGGER!1: J8.2, U1.8
!TRIGGER!2: J12.2, U2.8
!TRIGGER!3: J16.2, U3.8
!TRIGGER!4: J20.2, U5.8
!TRIGGER!5: J24.2, U6.8
!TRIGGER!6: J28.2, U7.8
!TRIGGER!7: J32.2, U8.8
!TRIGGER!8: J36.2, U9.8
!TRIGGER!9: J40.2, U10.8
!TRIGGER!10: J44.2, U11.8
!TRIGGER!11: J48.2, U12.8
!TRIGGER!12: J52.2, U13.8
!TRIGGER!13: J56.2, U14.8
!TRIGGER!14: J60.2, U15.8
!TRIGGER!15: J64.2, U16.8
!TRIGGER!16: J68.2, U17.8
!TRIGGER!17: J72.2, U18.8
!TRIGGER!18: J76.2, U19.8
!TRIGGER!19: J80.2, U20.8
!TRIGGER!20: J84.2, U21.8
!TRIGGER!21: J88.2, U22.8
!TRIGGER!22: J92.2, U23.8
!TRIGGER!23: J96.2, U24.8
BUZZER: R7.1, U4.6
BUZZER1: R20.1, U1.6
BUZZER2: R34.1, U2.6
BUZZER3: R48.1, U3.6
BUZZER4: R62.1, U5.6
BUZZER5: R76.1, U6.6
BUZZER6: R90.1, U7.6
BUZZER7: R104.1, U8.6
BUZZER8: R118.1, U9.6
BUZZER9: R132.1, U10.6
BUZZER10: R146.1, U11.6
BUZZER11: R160.1, U12.6
BUZZER12: R174.1, U13.6
BUZZER13: R188.1, U14.6
BUZZER14: R202.1, U15.6
BUZZER15: R216.1, U16.6
BUZZER16: R230.1, U17.6
BUZZER17: R244.1, U18.6
BUZZER18: R258.1, U19.6
BUZZER19: R272.1, U20.6
BUZZER20: R286.1, U21.6
BUZZER21: R300.1, U22.6
BUZZER22: R314.1, U23.6
BUZZER23: R328.1, U24.6
GND: C1.2, C2.2, J1.4, J2.1, J3.1, J6.3, POWER.C, Q1.1, Q1.4, Q2.1, Q2.4, STAT.1, U4.14
GND1: C3.2, C4.2, J4.1, J5.1, J7.4, J8.3, POWER1.C, Q4.1, Q4.4, Q6.1, Q6.4, STAT1.1, U1.14
GND2: C5.2, C6.2, J9.1, J10.1, J11.4, J12.3, POWER2.C, Q7.1, Q7.4, Q9.1, Q9.4, STAT2.1, U2.14
GND3: C7.2, C8.2, J13.1, J14.1, J15.4, J16.3, POWER3.C, Q10.1, Q10.4, Q12.1, Q12.4, STAT3.1, U3.14
GND4: C9.2, C10.2, J17.1, J18.1, J19.4, J20.3, POWER4.C, Q13.1, Q13.4, Q15.1, Q15.4, STAT4.1, U5.14
GND5: C11.2, C12.2, J21.1, J22.1, J23.4, J24.3, POWER5.C, Q16.1, Q16.4, Q18.1, Q18.4, STAT5.1, U6.14
GND6: C13.2, C14.2, J25.1, J26.1, J27.4, J28.3, POWER6.C, Q19.1, Q19.4, Q21.1, Q21.4, STAT6.1, U7.14
GND7: C15.2, C16.2, J29.1, J30.1, J31.4, J32.3, POWER7.C, Q22.1, Q22.4, Q24.1, Q24.4, STAT7.1, U8.14
GND8: C17.2, C18.2, J33.1, J34.1, J35.4, J36.3, POWER8.C, Q25.1, Q25.4, Q27.1, Q27.4, STAT8.1, U9.14
GND9: C19.2, C20.2, J37.1, J38.1, J39.4, J40.3, POWER9.C, Q28.1, Q28.4, Q30.1, Q30.4, STAT9.1, U10.14
GND10: C21.2, C22.2, J41.1, J42.1, J43.4, J44.3, POWER10.C, Q31.1, Q31.4, Q33.1, Q33.4, STAT10.1, U11.14
GND11: C23.2, C24.2, J45.1, J46.1, J47.4, J48.3, POWER11.C, Q34.1, Q34.4, Q36.1, Q36.4, STAT11.1, U12.14
GND12: C25.2, C26.2, J49.1, J50.1, J51.4, J52.3, POWER12.C, Q37.1, Q37.4, Q39.1, Q39.4, STAT12.1, U13.14
GND13: C27.2, C28.2, J53.1, J54.1, J55.4, J56.3, POWER13.C, Q40.1, Q40.4, Q42.1, Q42.4, STAT13.1, U14.14
GND14: C29.2, C30.2, J57.1, J58.1, J59.4, J60.3, POWER14.C, Q43.1, Q43.4, Q45.1, Q45.4, STAT14.1, U15.14
GND15: C31.2, C32.2, J61.1, J62.1, J63.4, J64.3, POWER15.C, Q46.1, Q46.4, Q48.1, Q48.4, STAT15.1, U16.14
GND16: C33.2, C34.2, J65.1, J66.1, J67.4, J68.3, POWER16.C, Q49.1, Q49.4, Q51.1, Q51.4, STAT16.1, U17.14
GND17: C35.2, C36.2, J69.1, J70.1, J71.4, J72.3, POWER17.C, Q52.1, Q52.4, Q54.1, Q54.4, STAT17.1, U18.14
GND18: C37.2, C38.2, J73.1, J74.1, J75.4, J76.3, POWER18.C, Q55.1, Q55.4, Q57.1, Q57.4, STAT18.1, U19.14
GND19: C39.2, C40.2, J77.1, J78.1, J79.4, J80.3, POWER19.C, Q58.1, Q58.4, Q60.1, Q60.4, STAT19.1, U20.14
GND20: C41.2, C42.2, J81.1, J82.1, J83.4, J84.3, POWER20.C, Q61.1, Q61.4, Q63.1, Q63.4, STAT20.1, U21.14
GND21: C43.2, C44.2, J85.1, J86.1, J87.4, J88.3, POWER21.C, Q64.1, Q64.4, Q66.1, Q66.4, STAT21.1, U22.14
GND22: C45.2, C46.2, J89.1, J90.1, J91.4, J92.3, POWER22.C, Q67.1, Q67.4, Q69.1, Q69.4, STAT22.1, U23.14
GND23: C47.2, C48.2, J93.1, J94.1, J95.4, J96.3, POWER23.C, Q70.1, Q70.4, Q72.1, Q72.4, STAT23.1, U24.14
unnamed: PWR_LED.1, R4.2
unnamed: Q2.5, R5.2
unnamed: POWER.A, R4.1
unnamed: D1.A, JP1.2, LS1.-, Q2.3, R9.P$2, R14.2, R17.2
unnamed: Q3.1, R7.2
unnamed: D1.C, LS1.+, Q3.3
unnamed: R6.2, STATUS.C
unnamed: R6.1, STAT.2
unnamed: POWER1.A, R18.1
unnamed: Q1.2, R13.2
unnamed: Q1.5, R12.2
unnamed: Q2.2, R8.2
unnamed: Q2.6, R17.1
unnamed: Q1.3, R14.1
unnamed: Q1.6, R9.P$1, R15.1
unnamed: JP1.1, R15.2
unnamed: PWR_LED1.1, R18.2
unnamed: D2.A, JP10.2, LS2.-, Q4.3, R24.2, R25.2, R28.P$2
unnamed: Q5.1, R20.2
unnamed: Q4.5, R19.2
unnamed: D2.C, LS2.+, Q5.3
unnamed: Q6.2, R23.2
unnamed: Q6.5, R22.2
unnamed: Q4.2, R21.2
unnamed: Q4.6, R24.1
unnamed: Q6.3, R25.1
unnamed: Q6.6, R26.1, R28.P$1
unnamed: R27.2, STATUS1.C
unnamed: R27.1, STAT1.2
unnamed: JP10.1, R26.2
unnamed: POWER2.A, R32.1
unnamed: PWR_LED2.1, R32.2
unnamed: D3.A, JP15.2, LS3.-, Q7.3, R38.2, R39.2, R42.P$2
unnamed: Q8.1, R34.2
unnamed: Q7.5, R33.2
unnamed: D3.C, LS3.+, Q8.3
unnamed: Q9.2, R37.2
unnamed: Q9.5, R36.2
unnamed: Q7.2, R35.2
unnamed: Q7.6, R38.1
unnamed: Q9.3, R39.1
unnamed: Q9.6, R40.1, R42.P$1
unnamed: R41.2, STATUS2.C
unnamed: R41.1, STAT2.2
unnamed: JP15.1, R40.2
unnamed: POWER3.A, R46.1
unnamed: PWR_LED3.1, R46.2
unnamed: D4.A, JP20.2, LS4.-, Q10.3, R52.2, R53.2, R56.P$2
unnamed: Q11.1, R48.2
unnamed: Q10.5, R47.2
unnamed: D4.C, LS4.+, Q11.3
unnamed: Q12.2, R51.2
unnamed: Q12.5, R50.2
unnamed: Q10.2, R49.2
unnamed: Q10.6, R52.1
unnamed: Q12.3, R53.1
unnamed: Q12.6, R54.1, R56.P$1
unnamed: R55.2, STATUS3.C
unnamed: R55.1, STAT3.2
unnamed: JP20.1, R54.2
unnamed: POWER4.A, R60.1
unnamed: PWR_LED4.1, R60.2
unnamed: D5.A, JP25.2, LS5.-, Q13.3, R66.2, R67.2, R70.P$2
unnamed: Q14.1, R62.2
unnamed: Q13.5, R61.2
unnamed: D5.C, LS5.+, Q14.3
unnamed: Q15.2, R65.2
unnamed: Q15.5, R64.2
unnamed: Q13.2, R63.2
unnamed: Q13.6, R66.1
unnamed: Q15.3, R67.1
unnamed: Q15.6, R68.1, R70.P$1
unnamed: R69.2, STATUS4.C
unnamed: R69.1, STAT4.2
unnamed: JP25.1, R68.2
unnamed: POWER5.A, R74.1
unnamed: PWR_LED5.1, R74.2
unnamed: D6.A, JP30.2, LS6.-, Q16.3, R80.2, R81.2, R84.P$2
unnamed: Q17.1, R76.2
unnamed: Q16.5, R75.2
unnamed: D6.C, LS6.+, Q17.3
unnamed: Q18.2, R79.2
unnamed: Q18.5, R78.2
unnamed: Q16.2, R77.2
unnamed: Q16.6, R80.1
unnamed: Q18.3, R81.1
unnamed: Q18.6, R82.1, R84.P$1
unnamed: R83.2, STATUS5.C
unnamed: R83.1, STAT5.2
unnamed: JP30.1, R82.2
unnamed: POWER6.A, R88.1
unnamed: PWR_LED6.1, R88.2
unnamed: D7.A, JP35.2, LS7.-, Q19.3, R94.2, R95.2, R98.P$2
unnamed: Q20.1, R90.2
unnamed: Q19.5, R89.2
unnamed: D7.C, LS7.+, Q20.3
unnamed: Q21.2, R93.2
unnamed: Q21.5, R92.2
unnamed: Q19.2, R91.2
unnamed: Q19.6, R94.1
unnamed: Q21.3, R95.1
unnamed: Q21.6, R96.1, R98.P$1
unnamed: R97.2, STATUS6.C
unnamed: R97.1, STAT6.2
unnamed: JP35.1, R96.2
unnamed: POWER7.A, R102.1
unnamed: PWR_LED7.1, R102.2
unnamed: D8.A, JP40.2, LS8.-, Q22.3, R108.2, R109.2, R112.P$2
unnamed: Q23.1, R104.2
unnamed: Q22.5, R103.2
unnamed: D8.C, LS8.+, Q23.3
unnamed: Q24.2, R107.2
unnamed: Q24.5, R106.2
unnamed: Q22.2, R105.2
unnamed: Q22.6, R108.1
unnamed: Q24.3, R109.1
unnamed: Q24.6, R110.1, R112.P$1
unnamed: R111.2, STATUS7.C
unnamed: R111.1, STAT7.2
unnamed: JP40.1, R110.2
unnamed: POWER8.A, R116.1
unnamed: PWR_LED8.1, R116.2
unnamed: D9.A, JP45.2, LS9.-, Q25.3, R122.2, R123.2, R126.P$2
unnamed: Q26.1, R118.2
unnamed: Q25.5, R117.2
unnamed: D9.C, LS9.+, Q26.3
unnamed: Q27.2, R121.2
unnamed: Q27.5, R120.2
unnamed: Q25.2, R119.2
unnamed: Q25.6, R122.1
unnamed: Q27.3, R123.1
unnamed: Q27.6, R124.1, R126.P$1
unnamed: R125.2, STATUS8.C
unnamed: R125.1, STAT8.2
unnamed: JP45.1, R124.2
unnamed: POWER9.A, R130.1
unnamed: PWR_LED9.1, R130.2
unnamed: D10.A, JP50.2, LS10.-, Q28.3, R136.2, R137.2, R140.P$2
unnamed: Q29.1, R132.2
unnamed: Q28.5, R131.2
unnamed: D10.C, LS10.+, Q29.3
unnamed: Q30.2, R135.2
unnamed: Q30.5, R134.2
unnamed: Q28.2, R133.2
unnamed: Q28.6, R136.1
unnamed: Q30.3, R137.1
unnamed: Q30.6, R138.1, R140.P$1
unnamed: R139.2, STATUS9.C
unnamed: R139.1, STAT9.2
unnamed: JP50.1, R138.2
unnamed: POWER10.A, R144.1
unnamed: PWR_LED10.1, R144.2
unnamed: D11.A, JP55.2, LS11.-, Q31.3, R150.2, R151.2, R154.P$2
unnamed: Q32.1, R146.2
unnamed: Q31.5, R145.2
unnamed: D11.C, LS11.+, Q32.3
unnamed: Q33.2, R149.2
unnamed: Q33.5, R148.2
unnamed: Q31.2, R147.2
unnamed: Q31.6, R150.1
unnamed: Q33.3, R151.1
unnamed: Q33.6, R152.1, R154.P$1
unnamed: R153.2, STATUS10.C
unnamed: R153.1, STAT10.2
unnamed: JP55.1, R152.2
unnamed: POWER11.A, R158.1
unnamed: PWR_LED11.1, R158.2
unnamed: D12.A, JP60.2, LS12.-, Q34.3, R164.2, R165.2, R168.P$2
unnamed: Q35.1, R160.2
unnamed: Q34.5, R159.2
unnamed: D12.C, LS12.+, Q35.3
unnamed: Q36.2, R163.2
unnamed: Q36.5, R162.2
unnamed: Q34.2, R161.2
unnamed: Q34.6, R164.1
unnamed: Q36.3, R165.1
unnamed: Q36.6, R166.1, R168.P$1
unnamed: R167.2, STATUS11.C
unnamed: R167.1, STAT11.2
unnamed: JP60.1, R166.2
unnamed: POWER12.A, R172.1
unnamed: PWR_LED12.1, R172.2
unnamed: D13.A, JP65.2, LS13.-, Q37.3, R178.2, R179.2, R182.P$2
unnamed: Q38.1, R174.2
unnamed: Q37.5, R173.2
unnamed: D13.C, LS13.+, Q38.3
unnamed: Q39.2, R177.2
unnamed: Q39.5, R176.2
unnamed: Q37.2, R175.2
unnamed: Q37.6, R178.1
unnamed: Q39.3, R179.1
unnamed: Q39.6, R180.1, R182.P$1
unnamed: R181.2, STATUS12.C
unnamed: R181.1, STAT12.2
unnamed: JP65.1, R180.2
unnamed: POWER13.A, R186.1
unnamed: PWR_LED13.1, R186.2
unnamed: D14.A, JP70.2, LS14.-, Q40.3, R192.2, R193.2, R196.P$2
unnamed: Q41.1, R188.2
unnamed: Q40.5, R187.2
unnamed: D14.C, LS14.+, Q41.3
unnamed: Q42.2, R191.2
unnamed: Q42.5, R190.2
unnamed: Q40.2, R189.2
unnamed: Q40.6, R192.1
unnamed: Q42.3, R193.1
unnamed: Q42.6, R194.1, R196.P$1
unnamed: R195.2, STATUS13.C
unnamed: R195.1, STAT13.2
unnamed: JP70.1, R194.2
unnamed: POWER14.A, R200.1
unnamed: PWR_LED14.1, R200.2
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

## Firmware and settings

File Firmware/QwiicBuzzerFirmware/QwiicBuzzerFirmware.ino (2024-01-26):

/*
  An I2C based Buzzer
  By Pete Lewis @SparkFun Electronics
  Jan 2024

  Based on original code by the following:
  Nathan Seidle and Fischer Moseley and Priyanka Makin
  SparkFun Electronics
  Date: July 31st, 2019

  SPDX-License-Identifier: MIT

  Copyright (c) 2023 SparkFun Electronics

  Qwiic Buzzer is an I2C based buzzer that accepts commands to turn on/off the buzzer.
  It also can set it's frequency, duration and volume.

  There is also an accompanying Arduino Library located here:
  https://github.com/sparkfun/SparkFun_Qwiic_Buzzer_Arduino_Library

  Feel like supporting our work? Buy a board from SparkFun!
  https://www.sparkfun.com/products/14641

  To install support for ATtiny84 in Arduino IDE: https://github.com/SpenceKonde/ATTinyCore/blob/master/Installation.md
  This core is installed from the Board Manager menu
  This core has built in support for I2C S/M and serial
  If you have Dave Mellis' ATtiny installed you may need to remove it from \Users\xx\AppData\Local\Arduino15\Packages

  To support 400kHz I2C communication reliably ATtiny84 needs to run at 8MHz. This requires user to
  click on 'Burn Bootloader' before code is loaded.

  Library Inclusion:
  Wire.h        Used for interfacing with the I2C hardware for responding to I2C events.
  EEPROM.h      Used for interfacing with the onboard EEPROM for storing and retrieving settings.
  sfeQwiicBuzzerFirmware.h      Used for configuring the behavior of the onboard BUZZER

  avr/sleep.h             Needed for sleep_mode which saves power on the ATTiny
  avr/power.hardware      Needed for powering down peripherals such as the ADC/TWI and Timers on the ATTiny
*/

#include <Wire.h>
#include <EEPROM.h>
#include "sfeQwiicBuzzerFirmware.h"

#include <avr/sleep.h> //Needed for sleep_mode
#include <avr/power.h> //Needed for powering down perihperals such as the ADC/TWI and Timers

#define kSfeQwiicBuzzerDeviceID 0x5E
#define kSfeQwiicBuzzerFirmwareVersionMajor 0x01 // Firmware Version. Helpful for tech support.
#define kSfeQwiicBuzzerFirmwareVersionMinor 0x00

#define kSfeQwiicBuzzerDefaultI2cAddress 0x34

#define kSfeQwiicBuzzerResonantFrequency 2730

uint8_t sfeQwiicBuzzerOldI2cAddress;

bool previousTriggerPinState = true;            // used to detect transitions from high to low on trigger pin.
uint8_t triggerPinLowCounter = 0;               // debounce trigger pin status counter
uint8_t triggerPinHighCounter = 0;              // debounce trigger pin status counter
#define kSfeQwiicBuzzerTriggerDebounceAmount 10 // the amount of digitalReads required to recognise a Trigger pin status

// Hardware connections
#if defined(__AVR_ATmega328P__)
// For developement on an Uno
const uint8_t volumePin0 = 3;
const uint8_t volumePin1 = 4;
const uint8_t volumePin2 = 5;
const uint8_t volumePin3 = 6;
const uint8_t buzzerPin = 9; // PWM
const uint8_t statusLedPin = 8;
const uint8_t triggerPin = 2;

#elif defined(__AVR_ATtiny84__)
const uint8_t volumePin0 = 9;
const uint8_t volumePin1 = 10;
const uint8_t volumePin2 = 1;
const uint8_t volumePin3 = 2;
const uint8_t buzzerPin = 7; // for use with tone()
const uint8_t statusLedPin = 0;
const uint8_t triggerPin = 5;
#endif

/// @brief Initialize the Qwiic Buzzer register map with default values
memoryMap registerMap{
  kSfeQwiicBuzzerDeviceID,             // id
  kSfeQwiicBuzzerFirmwareVersionMinor, // firmwareMinor
  kSfeQwiicBuzzerFirmwareVersionMajor, // firmwareMajor
  0x00,                                // buzzerToneFrequencyMSB
  0x00,                                // buzzerToneFrequencyLSB
  0x00,                                // buzzerVolume
  0x00,                                // buzzerDurationMSB
  0x00,                                // buzzerDurationLSB
  0x00,                                // buzzerActive
  0x00,                                // saveSettings
  0x00,                                // i2cAddress
};

/// @brief Set permissions on each register member (0=read-only, 1=read-write)
memoryMap protectionMap = {
  0x00, // id
  0x00, // firmwareMinor
  0x00, // firmwareMajor
  0xFF, // buzzerToneFrequencyMSB
  0xFF, // buzzerToneFrequencyLSB
  0x07, // buzzerVolume
  0xFF, // buzzerDurationMSB
  0xFF, // buzzerDurationLSB
  0x01, // buzzerActive
  0x01, // saveSettings
  0xFF, // i2cAddress
};

// Cast 32bit address of the object registerMap with uint8_t so we can increment the pointer
uint8_t *registerPointer = (uint8_t *)&registerMap;
uint8_t *protectionPointer = (uint8_t *)&protectionMap;

/// @brief Gets set when user writes an address. We then serve the spot the user requested.
volatile uint8_t registerNumber;

/// @brief Goes true when we receive new bytes from user. Causes things to update in main loop.
volatile boolean updateFlag = true;

/// @brief Initialize the onboard Buzzer
QwiicBuzzerFirmware buzzer;

//-=-=-=-=-=-=-=-=-=-=-=-=-=-=-=-=-=-=-=-=-=-=-=-=-=-=-=-=-=-=-=-=-=-=-=-=-=-=-=-=-=-=-=-=-=-

void setup(void)
{
  // Setup GPIO pins in the class
  buzzer.setupPins(volumePin0, volumePin1, volumePin2, volumePin3, statusLedPin, buzzerPin);

  // GPIO with internal pullup, goes low when user connects to GND
  pinMode(triggerPin, INPUT_PULLUP);

  /// @brief Used to measure how long the trigger pin has been held low. Must be
  /// held low for 1000ms to engage a factory reset
  int factoryResetPinLowCounter = 0;

  // Check for factory reset
  // If the user connects the TRIGGER pin low on boot-up, and continues to hold
  // it low for a full second, then perform a factory reset (write all settings
  // EEPROM to "fresh" values of 0xFF.
  while (digitalRead(triggerPin) == LOW)
  {
    delay(1);
    factoryResetPinLowCounter += 1;
    if (factoryResetPinLowCounter > 1000)
    {
      factoryReset();
      while (digitalRead(triggerPin) == LOW)
        ; // wait for trigger to go high
      break;
    }
  }

  // Disable ADC
  ADCSRA = 0;

  // Disable Brown-Out Detect
  MCUCR = bit(BODS) | bit(BODSE);
  MCUCR = bit(BODS);

  // Power down various bits of hardware to lower power usage
  set_sleep_mode(SLEEP_MODE_IDLE);
  sleep_enable();

#if defined(__AVR_ATmega328P__)

  for (int x = 0; x < 100; x++)
  {
    EEPROM.put(x, 0xFF);
  }
  Serial.begin(115200);
  Serial.println("Qwiic Buzzer");
  Serial.print("Address: 0x");
  Serial.println(registerMap.i2cAddress, HEX);
  Serial.print("Device ID: 0x");
  Serial.println(registerMap.id, HEX);

#endif

  // Load all system settings from EEPROM
  readSystemSettings(&registerMap);

  // Update Buzzer variables
  buzzer.updateFromMap(&registerMap);

  // Determine the I2C address we should be using
  // and begin listening on I2C bus
  startI2C(&registerMap);

  // Set old I2C address, so we can keep track for later, during a change.
  sfeQwiicBuzzerOldI2cAddress = registerMap.i2cAddress;
}

void loop(void)
{
  // Check to see if the I2C Address has been updated by software, set the appropriate address type flag
  if (sfeQwiicBuzzerOldI2cAddress != registerMap.i2cAddress)
  {
    sfeQwiicBuzzerOldI2cAddress = registerMap.i2cAddress;
  }

  // If buzzer is active and there is duration set, checkDuration
  // This will keep the buzzer buzzing until duration has been completed
  if (buzzer.active() && (registerMap.buzzerDurationLSB || registerMap.buzzerDurationMSB))
  {
    if (buzzer.checkDuration() == false)
    {
      buzzer.reset(&registerMap);
    }
  }

  // Check for updateFlag.
  // This is set inside interrupts (quickly, in order to keep the ISR zippy)
  if (updateFlag == true)
  {
    // Record anything new to EEPROM (for example, new I2C address)
    // Note, to save other settings (like frequency, duration or volume) the
    // user must also set the "saveSettings" register bit.
    // It can take ~3.4ms to write a byte to EEPROM so we do that here instead of in an interrupt
    recordSystemSettings(&registerMap);

    // Update settings from register map to actively used local variables
    buzzer.updateFromMap(&registerMap);

    // clear flag
    updateFlag = false;
  }

  // Check if TRIGGER has transitioned from high to low, and buzz!
  if ((digitalRead(triggerPin) == LOW) && (previousTriggerPinState == true))
  {
    // debounce
    triggerPinLowCounter += 1;

    if (triggerPinLowCounter > kSfeQwiicBuzzerTriggerDebounceAmount)
    {
      // Reset everything
      buzzer.reset(&registerMap);

      // set the map->buzzerActive register
      // This will be "caught" in updateFromMap and actually turn on the buzzer
      registerMap.buzzerActive = 0x01;

      updateFlag = true;               // this will cause an update in main loop
      triggerPinLowCounter = 0;        // reset debounce counter
      previousTriggerPinState = false; // keep track of status
    }
  }
  else if ((previousTriggerPinState == false) && (digitalRead(triggerPin) == HIGH)) // user has release trigger pin
  {
    // debounce
    triggerPinHighCounter += 1;

    if (triggerPinHighCounter > kSfeQwiicBuzzerTriggerDebounceAmount)
    {
      // If duration is set to zero, then we want this transition from LOW to HIGH to stop buzzer
      // Otherwise, duration will play out and stop the buzzer for us.
      if (buzzer.duration() == 0)
      {
        // Reset everything
        buzzer.reset(&registerMap);

        updateFlag = true; // this will cause an update in main loop
      }
      triggerPinHighCounter = 0;      // reset debounce counter
      previousTriggerPinState = true; // keep track of status
    }
  }

  // Stop everything and go to sleep. Wake up if I2C event occurs.
  sleep_mode();
}

/// @brief Update slave I2C address to what's configured with registerMap.i2cAddress
/// @param map memoryMap struct containing all qwiic buzzer register data
void startI2C(memoryMap *map)
{
  uint8_t address;

  // if the value is legal, then set it
  if (map->i2cAddress > 0x07 && map->i2cAddress < 0x78)
    address = map->i2cAddress;

  // if the value is illegal, default to the default I2C address for our platform
  else
    address = kSfeQwiicBuzzerDefaultI2cAddress;

  // save new address to the register map
  map->i2cAddress = address;

  // reconfigure Wire instance
  Wire.end();          // stop I2C on old address
  Wire.begin(address); // rejoin the I2C bus on new address

  // The connections to the interrupts are severed when a Wire.begin occurs, so here we reattach them
  Wire.onReceive(receiveEvent);
  Wire.onRequest(requestEvent);
}

/// @brief Reads the current system settings from EEPROM
/// If anything looks weird, reset setting to default value
/// @param map memoryMap struct containing all qwiic buzzer register data
void readSystemSettings(memoryMap *map)
{
  // Read what I2C address we should use
  EEPROM.get(kSfeQwiicBuzzerEepromLocationI2cAddress, map->i2cAddress);
  if (map->i2cAddress == 255)
  {
    map->i2cAddress = kSfeQwiicBuzzerDefaultI2cAddress; // By default, we listen for kSfeQwiicBuzzerDefaultI2cAddress
    EEPROM.put(kSfeQwiicBuzzerEepromLocationI2cAddress, map->i2cAddress);
  }

  // Error check I2C address we read from EEPROM
  if (map->i2cAddress < 0x08 || map->i2cAddress > 0x77)
  {
    // User has set the address out of range
    // Go back to defaults
    map->i2cAddress = kSfeQwiicBuzzerDefaultI2cAddress;
    EEPROM.put(kSfeQwiicBuzzerEepromLocationI2cAddress, map->i2cAddress);
  }

  // Tone Frequency
  uint16_t toneFrequency = 0; // used to store temp complete uint16_t from maps high/low bytes.

  EEPROM.get(kSfeQwiicBuzzerEepromLocationToneFrequency, toneFrequency);
  if (toneFrequency == 0xFFFF)
  {
    toneFrequency = kSfeQwiicBuzzerResonantFrequency; // Default to resonant frequency (2.73KHz)
    EEPROM.put(kSfeQwiicBuzzerEepromLocationToneFrequency, toneFrequency);
  }
  // extract MSB and LSB from complete uint16_t
  // put it into the registerMap for use everywhere
  uint8_t toneFrequencyMSB = ((toneFrequency & 0xFF00) >> 8);
  uint8_t toneFrequencyLSB = (toneFrequency & 0x00FF);
  map->buzzerToneFrequencyMSB = toneFrequencyMSB;
  map->buzzerToneFrequencyLSB = toneFrequencyLSB;

  // Duration
  uint16_t toneDuration = 0; // used to store temp complete uint16_t from maps high/low bytes.

  EEPROM.get(kSfeQwiicBuzzerEepromLocationDuration, toneDuration);
  if (toneDuration == 0xFFFF)
  {
    toneDuration = 0; // Default to zero (forever)
    EEPROM.put(kSfeQwiicBuzzerEepromLocationDuration, toneDuration);
  }
  // extract MSB and LSB from complete uint16_t
  // put it into the registerMap for use everywhere
  uint8_t toneDurationMSB = ((toneDuration & 0xFF00) >> 8);
  uint8_t toneDurationLSB = (toneDuration & 0x00FF);
  map->buzzerDurationMSB = toneDurationMSB;
  map->buzzerDurationLSB = toneDurationLSB;

  // Volume
  EEPROM.get(kSfeQwiicBuzzerEepromLocationVolume, map->buzzerVolume);
  if (map->buzzerVolume == 0xFF)
  {
    map->buzzerVolume = 4; // Default to full
    EEPROM.put(kSfeQwiicBuzzerEepromLocationVolume, map->buzzerVolume);
  }
}

/// @brief Record current settings in registerMap to EEPROM (only if different)
/// @param map memoryMap struct containing all qwiic buzzer register data
void recordSystemSettings(memoryMap *map)
{
  // I2C address is byte
  byte i2cAddr;

  // Error check the current I2C address
  if (map->i2cAddress >= 0x08 && map->i2cAddress <= 0x77)
  {
    // Address is valid

    // Read the value currently in EEPROM. If it's different from the memory map then record the memory map value to EEPROM.
    EEPROM.get(kSfeQwiicBuzzerEepromLocationI2cAddress, i2cAddr);
    if (i2cAddr != map->i2cAddress)
    {
      EEPROM.put(kSfeQwiicBuzzerEepromLocationI2cAddress, (byte)map->i2cAddress);
      startI2C(map); // Determine the I2C address we should be using and begin listening on I2C bus
    }
  }
  else
  {
    EEPROM.get(kSfeQwiicBuzzerEepromLocationI2cAddress, i2cAddr);
    map->i2cAddress = i2cAddr; // Return to original address
  }

  // if user has set bit 0 in the ""saveSettings" register, then record settings to EEPROM.
  if (map->saveSettings == 1)
  {
    uint16_t mapToneFrequency = map->buzzerToneFrequencyLSB | (map->buzzerToneFrequencyMSB << 8);
    EEPROM.put(kSfeQwiicBuzzerEepromLocationToneFrequency, mapToneFrequency);

    uint16_t mapDuration = map->buzzerDurationLSB | (map->buzzerDurationMSB << 8);
    EEPROM.put(kSfeQwiicBuzzerEepromLocationDuration, mapDuration);

    EEPROM.put(kSfeQwiicBuzzerEepromLocationVolume, map->buzzerVolume);

    // clear "saveSettings" bit, so it only happens once
    map->saveSettings = 0x00;
  }
}

/// @brief I2C interrupt, called when data has been received from an I2C controller
/// @param numberOfBytesReceived The number of bytes that a I2C controller has sent
void receiveEvent(int numberOfBytesReceived)
{
  // Get the memory map offset from the user
  registerNumber = Wire.read();

  // Begin recording the following incoming bytes to the temp memory map
  // starting at the registerNumber (the first byte received)
  for (uint8_t registerOffset = 0; registerOffset < numberOfBytesReceived - 1; registerOffset++)
  {
    // We might record it, we might throw it away
    uint8_t temp = Wire.read();

    if ((registerOffset + registerNumber) < sizeof(memoryMap))
    {
      // Clense the incoming byte against the read only protected bits
      // Store the result into the register map
      *(registerPointer + registerNumber + registerOffset) &= ~*(protectionPointer + registerNumber + registerOffset);       // Clear this register if needed
      *(registerPointer + registerNumber + registerOffset) |= temp & *(protectionPointer + registerNumber + registerOffset); // Or in the user's request (clensed against protection bits)
    }
  }

  if (numberOfBytesReceived > 1) // only update if we received a valid amount
  {
    updateFlag = true; // Update in the main loop
  }
}

/// @brief I2C interrupt, called when data has been requested by an I2C controller
/// The interrupt will respond with bytes starting from the last byte the user sent to us
/// This will write the entire contents of the register map struct starting from
/// the register the user requested, and when it reaches the end the I2C-controller
/// will read 0xFFs.
/// @param numberOfBytesReceived The number of bytes that a I2C controller has sent
void requestEvent()
{
  Wire.write((registerPointer + registerNumber), sizeof(memoryMap) - registerNumber);
}

/// @brief Perform a factory reset.
/// This will write all values in settings EEPROM to "fresh" values of 0xFF.
void factoryReset()
{
  // write settings EEPROM locations to 0xFF
  EEPROM.put(kSfeQwiicBuzzerEepromLocationI2cAddress, 0xFF);
  EEPROM.put(kSfeQwiicBuzzerEepromLocationToneFrequency, 0xFFFF);
  EEPROM.put(kSfeQwiicBuzzerEepromLocationVolume, 0xFF);
  EEPROM.put(kSfeQwiicBuzzerEepromLocationDuration, 0xFFFF);

  // blink the status LED three times to indicate that factory reset has completed.
  for (int i = 0; i < 3; i++)
  {
    digitalWrite(statusLedPin, HIGH);
    delay(100);
    digitalWrite(statusLedPin, LOW);
    delay(100);
  }
}

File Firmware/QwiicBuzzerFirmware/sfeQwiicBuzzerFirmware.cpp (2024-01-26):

/******************************************************************************
    sfeQwiicBuzzerFirmware.cpp

    By Pete Lewis @SparkFun Electronics
    Jan 2024

    Based on original code by the following:
    Nathan Seidle and Fischer Moseley and Priyanka Makin
    SparkFun Electronics
    Date: July 31st, 2019

    This file defines the QwiicBuzzerFirmware class, which provides an easy interface for
    handling how the BUZZER behaves, in addition to storing configuration variables.

    SPDX-License-Identifier: MIT

    Copyright (c) 2023 SparkFun Electronics

    Distributed as-is; no warranty is given.
******************************************************************************/

#include "sfeQwiicBuzzerFirmware.h"

void QwiicBuzzerFirmware::setupPins(uint8_t volPin0, uint8_t volPin1, uint8_t volPin2, uint8_t volPin3, uint8_t statPin, uint8_t buzzPin)
{
    _volumePin0 = volPin0;
    _volumePin1 = volPin1;
    _volumePin2 = volPin2;
    _volumePin3 = volPin3;
    _statusLedPin = statPin;
    _buzzerPin = buzzPin;

    // all volume settings output low - OFF
    pinMode(_volumePin0, OUTPUT);
    pinMode(_volumePin1, OUTPUT);
    pinMode(_volumePin2, OUTPUT);
    pinMode(_volumePin3, OUTPUT);
    digitalWrite(_volumePin0, LOW);
    digitalWrite(_volumePin1, LOW);
    digitalWrite(_volumePin2, LOW);
    digitalWrite(_volumePin3, LOW);

    pinMode(_statusLedPin, OUTPUT);
    digitalWrite(_statusLedPin, LOW);

    pinMode(_buzzerPin, OUTPUT);
    digitalWrite(_buzzerPin, LOW);
}

void QwiicBuzzerFirmware::updateFromMap(struct memoryMap *map)
{
    // check if any of the values are different, and update class variables
    bool different = false;
    if (map->buzzerVolume != _volume)
    {
        _volume = map->buzzerVolume;
        different = true;
    }

    uint16_t mapToneFrequency = map->buzzerToneFrequencyLSB | (map->buzzerToneFrequencyMSB << 8);
    if (mapToneFrequency != _toneFrequency)
    {
        _toneFrequency = mapToneFrequency;
        different = true;
    }

    uint16_t mapDuration = map->buzzerDurationLSB | (map->buzzerDurationMSB << 8);
    if (mapDuration != _duration)
    {
        _duration = mapDuration;
        different = true;
    }

    // if the previous statusFlag of the buzzer means it sitting "off",
    // then we want to check and see if the user just made it active,
    // and then turn on the buzzer (but only once).
    uint8_t mapBuzzerActive = map->buzzerActive;

    if ((mapBuzzerActive == 0x01) && ((_buzzerActiveFlag == false) || (different == true))) // this means we were off, and now the user wants to turn it on.
    {
        if (_duration > 0) // Duration is used, and we're starting a new buzz, so need to reset _buzzerStartTime.
            _buzzerStartTime = millis(); // used to know when to turn off the GND connection on the buzzer (aka the volume setting to zero).

        if (_toneFrequency != 0) // to avoid clicking sounds if the user wants to play a "rest" note (frequency set to 0)
            tone(_buzzerPin, _toneFrequency);
        else // User has changed frequency to 0, (aka the "rest" note).
            noTone(_buzzerPin);

        // volume control
        if (_toneFrequency != 0) // to avoid clicking sounds if the user wants to play a "rest" note (frequency set to 0)
        {
            // first, turn off all volumes, then turn on the only desired setting
            digitalWrite(_volumePin0, LOW);
            digitalWrite(_volumePin1, LOW);
            digitalWrite(_volumePin2, LOW);
            digitalWrite(_volumePin3, LOW);
            switch (_volume)
            {
            case 1: // setting 1 - aka "quietest" or "user"
                digitalWrite(_volumePin3, HIGH);
                break;
            case 2: // setting 2 - aka "mid-low"
                digitalWrite(_volumePin2, HIGH);
                break;
            case 3: // setting 3 - aka "mid-high"
                digitalWrite(_volumePin1, HIGH);
                break;
            case 4: // setting 4 - aka "loudest"
                digitalWrite(_volumePin0, HIGH);
                break;
            default: // off
                // do nothing, they are already turned off above
                break;
            }
        }

        // status LED control
        // only turn on when volume and frequency are both non-zero
        if( (_volume != 0) && (_toneFrequency != 0) ) 
            digitalWrite(_statusLedPin, HIGH);

        _buzzerActiveFlag = true;
    }
    else if ((mapBuzzerActive == 0x00) && (_buzzerActiveFlag == true)) // this means we are currently on, and the user wants to turn it off
        reset(map);
}

bool QwiicBuzzerFirmware::checkDuration()
{
    return (millis() - _buzzerStartTime < _duration); // we've surpassed duration, time to turn off
}

void QwiicBuzzerFirmware::reset(struct memoryMap *map)
{
    // Stop the tone.
    // Note, this could have already been stopped by tone's duration
    noTone(_buzzerPin);

    // Disable GND side connections
    digitalWrite(_volumePin0, LOW);
    digitalWrite(_volumePin1, LOW);
    digitalWrite(_volumePin2, LOW);
    digitalWrite(_volumePin3, LOW);

    // Clear the map->buzzerActive register
    map->buzzerActive = 0x00;

    // Turn off the status LED
    digitalWrite(_statusLedPin, LOW);

    // Update class variable of _buzzerActiveFlag to reflect reality
    _buzzerActiveFlag = false;
}

bool QwiicBuzzerFirmware::active()
{
    return _buzzerActiveFlag;
}

bool QwiicBuzzerFirmware::duration()
{
    return _duration;
}

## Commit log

2023-12-07 Layout started
    [SparkFun_Qwiic_Buzzer.brd, SparkFun_Qwiic_Buzzer.sch]
2023-12-08 Layout done
    [SparkFun_Qwiic_Buzzer.brd, SparkFun_Qwiic_Buzzer.sch]
2023-12-08 updated miso to poci
    both net names and board header silk
    [SparkFun_Qwiic_Buzzer.brd, SparkFun_Qwiic_Buzzer.sch]
2023-12-08 Aligned header to be breadboard friendly
    [SparkFun_Qwiic_Buzzer.brd]
2023-12-08 add ordering instructions
    [SparkFun_Qwiic_Buzzer.brd, SparkFun_Qwiic_Buzzer.sch]
2023-12-08 text only label for USER resistor
    [SparkFun_Qwiic_Buzzer.brd]
2023-12-08 INT pin anular ring correction
    [SparkFun_Qwiic_Buzzer.brd, SparkFun_Qwiic_Buzzer.sch]
2023-12-08 replace parts from old libraries
    -fids and gnd symbols
    [SparkFun_Qwiic_Buzzer.brd, SparkFun_Qwiic_Buzzer.sch]
2023-12-08 default i2c address is 0x34
    added note to sch.
    [SparkFun_Qwiic_Buzzer.sch]
2023-12-08 approve drc error
    [SparkFun_Qwiic_Buzzer.brd]
2023-12-08 more ordering instructions
    [SparkFun_Qwiic_Buzzer.brd]
2023-12-11 group review pre-meeting
    -add flyback diode
    -add tPlace lines to divide tightly packed passives
    -add 10uF cap on 3V3 rail
    -corrected name on I2C Jumper
    -Added JP1 to allow user to easily remove R15 resistor when using USER PTH resistor for volume control
    -fixes some acid traps on poci and rst headers
    -increased trace from USER resistor to BJT.
    -trigger net renames to have active low in the name
    [SparkFun_Qwiic_Buzzer.brd, SparkFun_Qwiic_Buzzer.sch]
2023-12-11 reduced size of qwiic logo and buzzer test on bottom silk
    [SparkFun_Qwiic_Buzzer.brd]
2023-12-12 Corrected GND header silk label
    -rotated GND header silk label to match others
    -updated VCC note in sch to show typically 3.3V via QWIIC.
    [SparkFun_Qwiic_Buzzer.brd, SparkFun_Qwiic_Buzzer.sch]
2023-12-12 Added note about SPI - only for programming
    -This product will not accept commands via SPI. These connections are only broken out for firmware programming.
    [SparkFun_Qwiic_Buzzer.sch]
2023-12-12 post review tweaks
    -removed INT pin feature (both header pin and pullup resistor)
    -changed TRIGGER pin to use POCI pin. It will be there for programming as needed, but this naming omits any mention of SPI, making it really clear this doesn't do SPI.
    [SparkFun_Qwiic_Buzzer.brd, SparkFun_Qwiic_Buzzer.sch]
2023-12-12 finalized resistor values on vol control
    [SparkFun_Qwiic_Buzzer.brd, SparkFun_Qwiic_Buzzer.sch]
2023-12-13 STAT LED moved to GPIO
    -This way it won't be dimmed by the buzzers frequency and can more precisely be controlled via firmware.
    [SparkFun_Qwiic_Buzzer.brd, SparkFun_Qwiic_Buzzer.sch]
2023-12-13 routing nudges
    [SparkFun_Qwiic_Buzzer.brd]
2023-12-14 Production Panel v10
    [SparkFun_Qwiic_Buzzer-Panel.GBL, SparkFun_Qwiic_Buzzer-Panel.GBO, SparkFun_Qwiic_Buzzer-Panel.GBP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]
2023-12-14 Bringing in copy of Button Firmware
2023-12-14 small tweaks to get hacked button working as buzzer
2023-12-14 final review tweaks - no copper changes
    -re-order position of 0.1uF and 10uF Caps
    -re-order vol resistors
    -redo measures so they are better
    -added QWIIC logo to sch
    [SparkFun_Qwiic_Buzzer.brd, SparkFun_Qwiic_Buzzer.sch]
2023-12-14 re-panelized and re-cammed
    -all gerbers showed no diffs, so we're good to go.
    [SparkFun_Qwiic_Buzzer-Panel.brd]
2023-12-22 name change ledconfig to buzzerconfig
2023-12-22 namechange ledBrightness to BuzzerVolume
2023-12-22 namechange ledpin to buzzerPin
2023-12-22 remove a lot of button specific stuff
    like interrupt stuff, que stuff, and LED pulsing/fading stuff
2024-01-11 removing some more button stuff and changing wording
2024-01-11 Status LED working
2024-01-11 trigger pin working
2024-01-17 updates, round 1
    -added header gaurds
    -#includes moved into buzzer.h
    -included <Arduino.h> in buzzer.h
    -constants naming updated
    -moved interrupt functions into main INO file
    -deleted interrupts.h file
    -cleaning up old comments
    -updating license to MIT
2024-01-17 on a fresh EEPROM, default to volume 4
    -so trigger pin works out of the box, even without running save settings example
2024-01-18 Duration bug
    -duration wasn't getting saved properly to EEPROM or updated from map. This led to settings not being effective when using TRIGGER pin.
    -Changed checkDuration to return true/false, and moved the call to reset outside of that funtion.
    -Changed a bit how trigger pin is handled in main loop. It now reacts properly to momentary vs one-shot mode.
2024-01-18 BOM change - control resistors changed to 100 ohm
    R7, R5, R17, R12, R9
    [SparkFun_Qwiic_Buzzer.brd, SparkFun_Qwiic_Buzzer.sch]
2024-01-22 incrementing device ID
    -to differentiate it from other qwiic products with device IDs (the button is the only one I could find and its was 0x5D)
2024-01-23 Tested SLEEP_MODE_PWR_DOWN and it stops responding to I2C
2024-01-23 default case catch on volume switch
2024-01-23 status LED can just stat OUTPUT all the time
2024-01-23 Trigger pin now a non-blocker and reacts to transitions
    -Trigger pin now reacts to debounce transitions, and so do not block any incoming I2C register writes
2024-01-23 updateFlag should only be set if numberOfBytesReceived > 1
    when we receive an I2C event message, updateFlag should only be set if numberOfBytesReceived > 1
2024-01-24 factory reset added
    -hold down trigger pin on boot up (for 1000ms), and this will reset settings EEPROM values to 0xFF.
2024-01-25 minor final-ish updates
    -reduced some code two single lines when dealing with MSB and LSB of a setting
    -removed unnecessary {} from single line statements
    -status LED now only comes on when there both non-zer values for volume and frequency.
    -updated some types (uint32_t and bool)

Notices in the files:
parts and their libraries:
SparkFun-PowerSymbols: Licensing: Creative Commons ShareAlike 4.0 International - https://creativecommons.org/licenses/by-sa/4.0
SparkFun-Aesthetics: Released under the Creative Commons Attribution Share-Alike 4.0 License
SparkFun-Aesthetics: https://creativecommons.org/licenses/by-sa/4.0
